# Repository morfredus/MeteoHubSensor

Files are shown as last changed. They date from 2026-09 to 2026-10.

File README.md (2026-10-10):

# MeteoHubSensor





> 🇫🇷 Version française : [README.fr.md](README.fr.md)

Standalone outdoor weather probe, linked over **ESP-NOW** to the **MeteoHub** station. Target board: **ESP32-S3 Super Mini** (RGB LED, no screen).

---

## 1. Responsibility

**MeteoHubSensor** has a single responsibility: **measure the outdoor environment and transmit its raw metrics over ESP-NOW**.

This node is **not a new morfSystem component**. No web server, no local history.

### Roles:
- **Super Mini (Outdoor)**: *"I measure, I blink the status, I transmit."*
- **MeteoHub**: *"I receive, validate, store, display and expose."*

---

## 2. ESP-NOW architecture

```
              ┌─────────────────┐
              │  ESP32-S3       │
              │  MeteoHub       │
              └────────┬────────┘
                       │ ESP-NOW
              ┌────────▼────────┐
              │  Super Mini     │
              │  RGB LED        │
              │  AHT20 / BMP280 │
              └────────┬────────┘
                       │
              ┌────────┴────────┐
              ▼                 ▼
         Temperature        Humidity
```

### Changing hub: pairing with a long press on BOOT

The probe talks to **a single** MeteoHub, in unicast. That hub's MAC is stored in
the probe's NVS: there is no need to know it at build time, nor to reflash to
change hub.

1. Leave **only** the MeteoHub to pair powered on within radio range
   (MeteoHub **≥ 1.46.0**).
2. With the probe running, hold **BOOT for about 3 s**, until the LED turns
   **solid blue**, then **release**: pairing starts on release. A press longer
   than 10 s is ignored (button considered stuck). Do not hold BOOT while
   plugging the probe in: that is the ESP32 flashing mode.
3. The probe sweeps channels 1 to 13 asking "who is a hub?". The hub answers with
   its identity and MAC; the probe confirms in unicast and waits for the hub's
   acknowledgement.
4. **3 green flashes**: paired, the new MAC is in NVS and measurements go to this
   hub in unicast. **3 red flashes**: failure, the previous association is **kept
   as it was**.

Rules:

- **Deliberate only.** A hub that is off or out of range never triggers a change
  of receiver: the probe keeps its measurements pending and keeps aiming at its
  hub.
- **A failure erases nothing.** Until a new hub has answered AND acknowledged the
  confirmation, the probe keeps the old MAC (in NVS and in memory).
- **Several hubs in range.** If two different hubs answer during the sweep, the
  probe refuses (red flashes) rather than pick one at random. Once paired, the
  other hubs can be switched back on: the probe finds ITS hub's channel through
  the exact BSSID of its "MH-NOW" access point, no longer through the first
  "MH-NOW" it sees.
- **No duplicate, no gap.** The confirmation carries the last measurement number
  acknowledged by the old hub: the new hub resumes from there and only receives
  the measurements still pending.
- **Stuck button = no effect.** A permanent press (an enclosure pressing the
  button, moisture on GPIO0) is never released: it starts no pairing, and the
  button wake-up is not even armed while GPIO0 stays low. Measurements carry on
  normally.
- Search bounded to **60 s**. A short press is ignored.
- The hub (≥ 1.47.0) **only archives the probe that chose it**: a bench probe
  powered on next to it can no longer mix its readings with the outdoor ones. The
  press wakes the probe from sleep; it then goes back to sleep for the remaining
  time, without shifting the measurement cadence.

Without a stored pairing (new probe, erased flash), the probe **sends nothing**:
`ESPNOW_RECEIVER_MAC` (`include/config.h`) is zero since 0.25.0. It keeps its
measurements pending and no longer scans channels until a long press on BOOT has
paired it. A hard-coded MAC would have targeted one specific hub, and after
swapping hubs (production ↔ test bench) an erased probe would have sent its
readings to the wrong hub.

### Local buffer: no measurement lost, without draining the battery

Each measurement is written to flash **before** it is sent, then kept until the
hub acknowledges it. If the hub is off or out of range, the probe later resends
what is missing, in order, at most 10 measurements per wake-up. Retention: 30
days of pending measurements.

Since 0.24.0 this buffer is a **segmented journal**: one small file per day of
measurements (`/mhs/<seq>.seg`), written by appending only. The acknowledgement
watermark lives in NVS, and a fully acknowledged segment is deleted. The former
buffer, a single 276 KB file, was copied in full by LittleFS at every
measurement: 4.5 s measured, radio on. On the first boot in 0.24.0, the
measurements still pending in the old file are taken over, then it is erased.

---

## 3. Hardware

The pinout lives in `include/board_config.h`, selected by the `SENSOR_BOARD_S3`
define set by the PlatformIO environment.

**ESP32-S3 Super Mini** (env `sonde-supermini`)
- 4 MB flash + 2 MB quad PSRAM (unused), native USB CDC. **No screen** (status on the LED).
- Status = RGB LED on GPIO 48 (blue acquisition, green OK, red error).
- **I2C**: SDA = GP8, SCL = GP9. Battery: Li-ion, 3.3 V regulator module, 100k/100k divider on GP4.
- ESP-NOW capped at **11 dBm** (hardware constraint confirmed by testing: full power = no ACK).
- **Sensors**: DHT22 on GP1 (reference for temperature and humidity, no fallback), BMP280 (pressure only; the AHT20 of the module is no longer read). Anemometer reserve on GP5.
- Details (French): [`docs/cablage.md`](docs/cablage.md).

---

## 4. RGB LED

- **Blue**: boot and acquisition.
- **Green**: delivery confirmed (the hub acknowledged, unicast ACK).
- **Red**: not delivered (no ACK from the hub).
- **Solid blue** (after ~3 s holding BOOT): pairing in progress.
- **3 green / red flashes**: pairing succeeded / failed (association unchanged).

---

## 5. Build and flash

1. Copy `include/secrets_example.h` to `include/secrets.h` **in this project**.

```bash
# ESP32-S3 Super Mini
pio run -e sonde-supermini
pio run -e sonde-supermini -t upload
pio run -e sonde-supermini -t monitor
```

If the serial port does not show up: hold BOOT, tap RESET, release BOOT.

---

## 6. Author & License

Developed by **morfredus** for the **MeteoHub** weather station.
License: **GPL v3**.

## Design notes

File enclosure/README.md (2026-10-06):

# enclosure

Premiere version d'un **mini ecran de Stevenson** pour la sonde, a imprimer en 3D.

- `stevenson-shelter-v1.scad` : modele OpenSCAD (V8), adapte du plan traditionnel a l echelle de la sonde.
  Volume interieur 110 x 90 x 110 mm, caisson exterieur 130 x 110 x 130 mm, 10 lames par face
  (110 x 8 x 4 mm, inclinees a 40 degres, pas de 11,2 mm), exterieur toujours plus bas sur les quatre faces.
- `stevenson-reference-plan.jpg` : page de reference du plan traditionnel (« La construction d une station
  meteo »). Document tiers : a garder dans ce depot prive, a ne pas publier tel quel.

Etat : premier jet, non imprime ni teste. Le but est de limiter l echauffement solaire du capteur
(variations brutales de temperature observees en plein apres-midi) tout en gardant une bonne circulation d air.

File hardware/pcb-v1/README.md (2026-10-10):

# Carte v1 de MeteoHubSensor (projet KiCad 10)

Platine dessinée pour remplacer la v1 montée sur platine à bandes (uPesy) : même schéma, mais gravée,
avec l'ESP32-S3 Super Mini sur supports pour pouvoir l'échanger sans dessoudage.

Ouvrir `meteohubsensor-v1.kicad_pro` avec KiCad 10.0.x. Fichiers : schéma, PCB routé (66 x 50 mm, deux
couches, plan de masse GND sur les deux faces), bibliothèque `morfsensor` (symboles et empreintes propres au projet).

## Ce que porte la carte

| Réf. | Rôle | Reliée à |
| :--- | :--- | :--- |
| U1 | ESP32-S3 Super Mini N4R2 sur 2 supports femelles 1x9 | voir ci-dessous |
| U2 | Module abaisseur 3,3 V (Youmi, SOT-223) | VIN = + accu, VOUT = rail 3V3 |
| J1 | Accu (JST-XH 2 broches : + / -) | VBAT, GND |
| J2 | BMP280 (JST-XH 4 broches : 3V3, SCL, SDA, GND) | GP9 (SCL), GP8 (SDA) |
| J3 | DHT22 (JST-XH 3 broches : 3V3, DATA, GND) | GP1 |
| J4 | Anémomètre, futur (3V3, IMPULSION, GND) | GP5 |
| J5 | Pluviomètre, futur (3V3, IMPULSION, GND) | GP7 |
| J6 | Girouette, future (3V3, ADC, GND) | GP2 |
| R1, R2 | Pont 100 kohm / 100 kohm sur le + accu, avant le régulateur | milieu = GP4 |
| C3 | 100 nF sur le noeud du pont (stabilise la lecture ADC) | GP4 / GND |
| C1, C2 | 100 nF céramique + 220 uF électrolytique, collés aux broches 3V3/GND du S3 | rail 3V3 |
| R3 | 10 kohm de rappel du DHT22 (omettre avec un module 3 broches qui l'embarque) | DATA / 3V3 |
| H1 à H4 | Trous de fixation M3 | |

Le régulateur alimente la broche **3V3** du S3 (pas la 5V), comme sur la v1 actuelle. Broches du S3 laissées
libres : TX, RX, GP3, GP6, 5V, GP10 à GP13.

## Masse et modèles 3D

La masse (GND) est un plan de cuivre sur les deux faces : toutes les broches GND des connecteurs et des
composants s'y raccordent par leurs pastilles traversantes, sans piste dédiée. Seules l'alimentation et les signaux
sont tracés. Des pistes GND explicites ont été
essayées puis retirées : elles alourdissaient le dessin sans rien apporter, le plan relie déjà tout.
Les empreintes `ESP32-S3_SuperMini_Socket` et `Regulator_Module_3V3` embarquent un modèle 3D simplifié
(`morfsensor.3dshapes/`) : supports et module avec USB-C et antenne, platine du régulateur avec SOT-223.

## Brochage des connecteurs JST-XH

Broche 1 à gauche (côté de l'ergot carré de l'embase), vue de dessus, détrompeur vers le bas.

| Connecteur | Broche 1 | Broche 2 | Broche 3 | Broche 4 | Référence suivie |
| :--- | :--- | :--- | :--- | :--- | :--- |
| J1 accu | + accu | - accu | | | rouge (+) puis noir (-), usage courant des accus Li-ion |
| J2 BMP280 | 3V3 | SCL | SDA | GND | + puis signaux puis GND, comme les autres ; SCL et SDA se relient sans croisement |
| J3 DHT22 | 3V3 | DATA | GND | | ordre de la fiche technique du DHT22 / AM2302 (VDD, DATA, GND) |
| J4 anémomètre | 3V3 | IMPULSION | GND | | même ordre que J3 |
| J5 pluviomètre | 3V3 | IMPULSION | GND | | même ordre que J3 |
| J6 girouette | 3V3 | ADC | GND | | même ordre que J3 |

Les modules BMP280 courants sont étiquetés dans un autre ordre (VCC, GND, SCL, SDA) : les câbles se sertissent à
l'ordre du connecteur de la carte, pas à celui du module.

## Orientation du module régulateur

Vue de dessus, broches vers le bas (soudées sur la carte), IN à gauche et OUT à droite : sur chaque paire,
VIN (gauche) et VOUT (droite) sont sur la broche du bas, GND sur la broche du haut.

## Repères des broches du S3

Les numéros de pastilles de U1 sont les repères imprimés sur le module, vue de dessus, USB en haut : à
gauche de haut en bas TX, RX, 1, 2, 3, 4, 5, 6, 7 ; à droite de haut en bas 5V, GND, 3V3, 13, 12, 11, 10, 9, 8.
Pastille 8 = GPIO8 = SDA, pastille 9 = GPIO9 = SCL, et ainsi de suite : aucune table de correspondance à tenir.
J6 (girouette) ne porte que le signal brut sur GP2 : le pont diviseur propre à la girouette reste à définir
avec le firmware.

## Antenne

Le S3 est implanté **USB vers l'intérieur** : l'antenne céramique se retrouve au **bord bas** de la carte.
Une zone d'exclusion (cuivre, pistes, vias, plan de masse, sur les deux faces) couvre l'espace sous l'antenne
et jusqu'au bord. Aucune piste n'approche l'antenne : les signaux des deux rangées partent vers l'extérieur.

Limite connue : l'USB du module est tourné vers l'intérieur de la carte. Pour flasher, enlever le module de
ses supports (c'est l'intérêt de la prise).

## Cotes relevées sur les modules

- **ESP32-S3 Super Mini** : 15,9 mm hors tout entre les deux rangées de broches, soit 15,24 mm entre axes (broche de
  0,64 mm), pas de 2,54 mm comme sur une platine d'essai. Empreinte `ESP32-S3_SuperMini_Socket`.
- **Module régulateur** : circuit de 25,6 x 11,3 mm. Broches standard (0,64 mm) sur la grille de 2,54 mm, comme les
  deux modules qui entrent dans une platine d'essai : deux paires espacées de 22,86 mm entre axes (9 pas) dans la
  longueur, pas de 2,54 mm dans chaque paire (3 mm hors tout dans la largeur). Empreinte `Regulator_Module_3V3`.
  La position des paires dans la largeur du circuit est supposée centrée : elle ne change que le contour dessiné,
  pas le perçage.

## À vérifier avant fabrication

1. **Module régulateur** : vérifier que son orientation réelle (IN à gauche, VIN sur la broche du bas) correspond à
   l'empreinte, en le posant sur la carte imprimée ou sur un gabarit.
2. **Connecteurs** : les câbles existants ne suivent pas forcément cet ordre ; les recréer au brochage du tableau.

Rappel du point de vigilance de `docs/cablage.md` : la plage d'entrée annoncée du module (4,5 à 7 V) est
au-dessus de celle d'un accu Li-ion. À mesurer sur banc avant de figer la carte.

## Contrôles passés (KiCad 10.0.7, `kicad-cli`)

- ERC : 0 violation.
- DRC avec parité schéma/PCB : 0 erreur, 0 piste non connectée. Restent des avertissements de sérigraphie
  (textes proches des contours de connecteurs).

Les fichiers ont été générés par script puis vérifiés par ces commandes ; les ouvrir une fois dans KiCad et
lancer `Fichier > Enregistrer` les remet au format exact de l'éditeur.

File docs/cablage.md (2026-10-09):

# Câblage et fonctionnement - MeteoHubSensor

Sonde météo extérieure autonome, reliée à la station **MeteoHub** par **ESP-NOW**.
Carte cible : **ESP32-S3 Super Mini** (`sonde-supermini`) - LED RGB seule (pas d'écran,
pour réduire la consommation), TX ESP-NOW plafonnée (11 dBm).

> La liaison est un **unicast** vers la MAC du hub : chaque envoi reçoit un accusé
> de réception matériel (ACK). La carte plafonne sa puissance d'émission (l'antenne
> PCB du Super Mini est mal adaptée : à pleine puissance, le hub n'acquitte pas).
> Le niveau se règle dans `include/config.h`.
> Antenne filaire essayée en prod depuis le 2026-10-06 : voir `docs/notes.md`, section 5.

Le brochage vit dans `include/board_config.h` (sélectionné par `SENSOR_BOARD_S3`) et
les réglages dans `include/config.h`.

---

## 1. Brochage - ESP32-S3 Super Mini

USB natif sur GPIO 19/20. BOOT sur GPIO 0. Straps 45/46 (GP46 input-only).

| Broche | GPIO | Usage firmware |
| :--- | :--- | :--- |
| **3V3** | -- | Alim capteurs I2C |
| **GND** | -- | Masse |
| **GP8** | 8 | I2C **SDA** (BMP280 ; AHT20 non lu) |
| **GP9** | 9 | I2C **SCL** |
| **GP48** | 48 | LED RGB **WS2812** onboard (pas GP46) |
| **GP0** | 0 | Bouton **BOOT** |
| **GP4** | 4 | ADC batterie (`PIN_BATTERY_ADC = 4`) : pont 100k/100k depuis le **+ accu** (avant le régulateur 3,3 V) |
| **GP1** | 1 | DHT22 DATA (référence température et humidité) |
| **GP2** | 2 | Girouette ADC (réserve) |
| **GP7** | 7 | Pluviomètre (réserve) |
| **GP10** | 10 | ADC auxiliaire (réserve) |
| **GP5** | 5 | Anémomètre (réserve) |
| **GP6** | 6 | Libre |

- **Pas d'écran** : le statut passe par la LED RGB et le log USB CDC.
- **TX ESP-NOW plafonnée à 11 dBm** : à pleine puissance, le hub n'acquitte aucune
  trame (antenne PCB du Super Mini mal adaptée). Réglable via le menu de `config.h`
  (`SENSOR_TX_POWER_LEVEL` ; la carte le demande via `SENSOR_NEEDS_TX_LIMIT`).
- La LED RGB onboard est sur **GPIO 48**. Le pinout constructeur annote parfois
  DIN WS2812 = GP46 : sur ESP32-S3, GP46 ne peut pas la piloter. Si la LED reste
  éteinte après flash, tester GPIO 47 (certains clones Lolin).

---

## 2. Capteurs I2C

```
Carte                     Module BMP280 / AHT20
┌──────────┐              ┌─────────────────────┐
│      3V3 ├─────────────►│ VCC (3.3V)          │
│      GND ├─────────────►│ GND                 │
│  SDA     ├─────────────►│ SDA                 │
│  SCL     ├─────────────►│ SCL                 │
└──────────┘              └─────────────────────┘
```

- SDA/SCL : **GP8/GP9**.
- Adresses : AHT20 = 0x38, BMP280/BME280 = 0x76 ou 0x77.
- Pull-up I2C : la plupart des modules AHT/BMP les intègrent ; sinon 4,7 kΩ vers 3V3.

---

## 3. Alimentation batterie

**Module régulateur 3,3 V + accu Li-ion** (cellule 3,7 V, 3000 mAh depuis le 2026-10-03).
Un petit module **Youmi « 3.3 V DC/DC abaisseur »** (boîtier SOT-223, une LED sur la sortie,
bornes IN + GND et OUT + GND en 2 broches, 26 x 12 x 12 mm) abaisse la tension de l'accu en un
**3,3 V** pour la carte. Annoncé par le vendeur : entrée **4,5 à 7 V CC**, sortie 3,3 V CC,
800 mA. Le
même module équipe la v1 (prod) et la v2 (banc), voir la section 5.

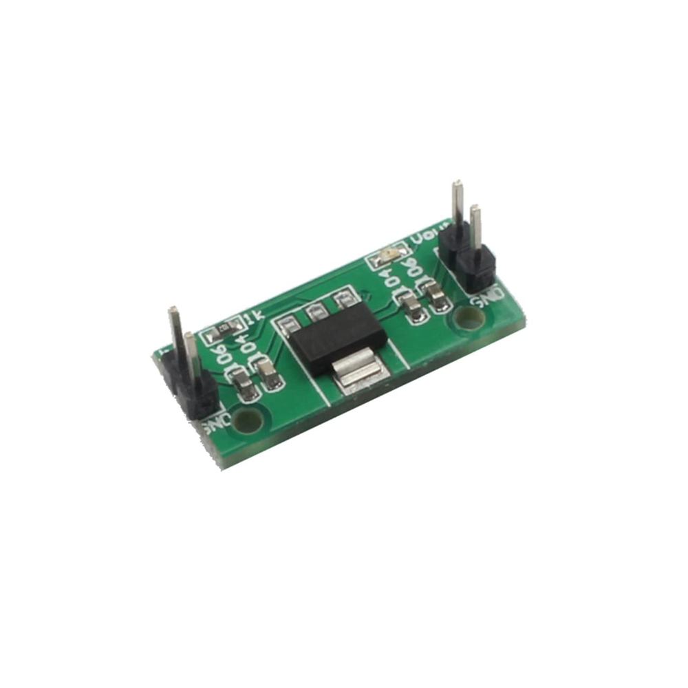
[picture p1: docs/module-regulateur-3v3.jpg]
Module régulateur 3,3 V


Câblage du module, identique sur la v1 et la v2 : l'**accu** est branché sur **VIN et GND** du
régulateur ; le module distribue le **3,3 V** (VOUT) et la **masse** (GND) à la carte.

Il remplace le module **Breadvolt** (boost AP2004H) des premières versions, qui semblait
décrocher à la charge très faible du deep sleep (voir l'essai light sleep dans
`include/config.h`). Le Breadvolt n'est plus monté sur la carte de prod.

**Charge de l'accu.** Le Breadvolt gérait lui-même l'accu (protection décharge 2,4 V, charge
4,28 V, LEDs CHG/PWR). Ce n'est plus le cas : le module régulateur ne fait ni charge ni
protection. L'accu est chargé **hors de la sonde, dans un chargeur de bureau** ; il n'y a **pas de
charge par USB** dans cette version. L'usage visé est de disposer de **deux accus** et de
remplacer l'accu usé par l'accu chargé quand c'est nécessaire.

> **Point de vigilance (à mesurer)** : la plage d'entrée annoncée du module (4,5 à 7 V) est
> **au-dessus** de celle d'un accu Li-ion (2,6 à 4,2 V). Hors plage, la sortie n'est plus un 3,3 V
> régulé : elle suit l'accu, diminuée de la tension de déchet (dropout) du régulateur. Le S3
> décroche alors bien avant que l'accu soit vide (brownout vers 2,4 à 3,0 V de rail). Mesurer
> VOUT en fonction de la tension d'accu, sur le banc, pour connaître l'accu minimal utilisable et
> le comparer aux seuils d'alerte de MeteoHub (3,40 V puis 3,20 V).

- Le 3,3 V régulé est **constant** : le mesurer ne dirait rien de l'accu. On tape donc
  la **cellule**, **avant** le régulateur, au **+ accu** (multimètre ~4,0 V en charge).
- Cet accu monte à **4,28 V** en pleine charge : il ne doit **jamais** arriver brut sur
  la pin (limite ADC du S3 ~3,3 V). Un **pont 100 kΩ / 100 kΩ** divise la tension par
  deux et GP4 lit le point milieu :

  ```
  + accu ──[R1 100k]──┬── GP4 (ADC1)
                      │
                   [R2 100k]
                      │
                     GND
  ```

  GP4 voit ~2,0 V pour 4,0 V accu ; le firmware remultiplie par le ratio du pont
  (`BATTERY_DIVIDER_RATIO = 2,0`) et convertit en pourcentage par une **courbe de charge Li-ion par paliers**
  (`include/battery_curve.h`, testée par `pio test -e native`), pas par une droite : à 3,7 V
  il reste ~15 %, pas 69 %.
  `PIN_BATTERY_ADC = 4` (activé le 2026-09-15).
- Le pont draine en continu ~4,0 V / 200 kΩ ≈ **20 µA**, négligeable devant les
  réveils d'émission.
- **Accu actuel (2026-10-03)** : Li-ion 3,7 V **3000 mAh** (remplace le 14500 de 500 mAh).
- **Calibration fine** : si la tension rapportée par la sonde diffère de
  ton multimètre (tolérance des résistances + offset ADC), poser
  `BATTERY_VREF_CALIBRATION = tension_multimètre / tension_rapportée` (× facteur actuel) dans
  `board_config.h`. **Posé le 2026-10-03 : 1,036** (moyenne de deux relevés multimètre / sonde : 3,927 V pour 3,98 V et 4,074 V pour 4,14 V ; résidu < 0,3 %). À revérifier à pleine charge stable et à mi-charge.
- Filet de sécurité : quand l'accu se vide, le pourcentage tombe à 0 % (0 % calé à
  2,6 V, **seuil confirmé**, 0,2 V au-dessus de l'ancienne coupure 2,4 V du Breadvolt), puis la
  sonde s'arrête (MeteoHub voit **OUT absent**). Voir le point de vigilance ci-dessus : le rail 3,3 V
  peut décrocher avant que l'accu atteigne ce seuil.

---

## 4. LED de statut (WS2812 / NeoPixel)

La carte porte **une LED RGB adressable WS2812** (NeoPixel), pas une simple LED. Le
firmware l'utilise comme **témoin d'activité et de résultat d'émission**, en luminosité
douce (pour ne pas éblouir de nuit ni trop consommer). Il n'y a **pas d'écran** : cette
LED est le seul retour visuel local.

| Couleur | Quand | Signification |
| :--- | :--- | :--- |
| 🔵 **Bleu** | Au démarrage, puis pendant **chaque acquisition** de mesure | « Je travaille » : lecture des capteurs et préparation de la trame en cours |
| 🟢 **Vert** (bref) | Juste après l'envoi ESP-NOW, si le hub a **accusé réception** | La trame est **livrée** (ACK reçu du hub) |
| 🔴 **Rouge** (bref) | Juste après l'envoi ESP-NOW, si **aucun ACK** n'est revenu | La trame **n'a pas été livrée** (hub hors de portée / éteint) |
| 🔴 **Rouge fixe** | Au boot, si l'init ESP-NOW échoue | Radio ESP-NOW indisponible (défaut au démarrage) |
| 🔵 **Bleu fixe** | Après ~3 s d'appui sur **BOOT** | Relâcher : l'appairage démarre au relâchement (recherche d'un hub, 60 s max). Au-delà de 10 s d'appui, rien ne se passe (bouton coincé) |
| 🟢 **3 éclairs verts** | Fin d'appairage | Nouveau hub enregistré, mesures redirigées vers lui |
| 🔴 **3 éclairs rouges** | Fin d'appairage | Aucun hub, plusieurs hubs, ou pas d'accusé : **association inchangée** |
| ⚫ **Éteinte** | Au repos entre deux mesures (et avant la mise en veille) | Rien à signaler / cycle terminé |

Précisions importantes :

- **Vert = trame réellement livrée.** L'envoi est un **unicast** vers la MAC du hub :
  la couche radio renvoie un ACK matériel. Le vert confirme donc que MeteoHub a bien
  reçu la trame (et non seulement qu'elle est partie) ; le rouge signale l'absence
  d'ACK (hub éteint, hors de portée, ou mauvais canal).
- Le clignotement vert/rouge est **court** (~60 ms) : à chaque cycle de mesure
  (5 min par défaut), on voit un bref éclat, puis la LED s'éteint.
- En **mode veille profonde** (si activé), la LED est éteinte avant le sommeil pour ne
  rien consommer ; chaque réveil rejoue la séquence bleu → vert/rouge.

Le pilotage est dans `src/modules/power_manager.cpp` (`setLedColor`, `blinkStatus`,
`turnOffLed`), déclenché depuis `src/main.cpp`.

---

## 5. Cartes v1 et v2

Deux platines à bandes portent le même montage : un ESP32-S3 Super Mini sur barrettes
femelles, le module régulateur 3,3 V, le pont de mesure de batterie (100 kΩ / 100 kΩ vers GP4),
un condensateur électrolytique et une céramique près de l'alimentation, et **trois prises JST**
(accu, signaux I2C, alimentation du capteur).

### v1 : platine uPesy, sonde de production (boîtier extérieur)

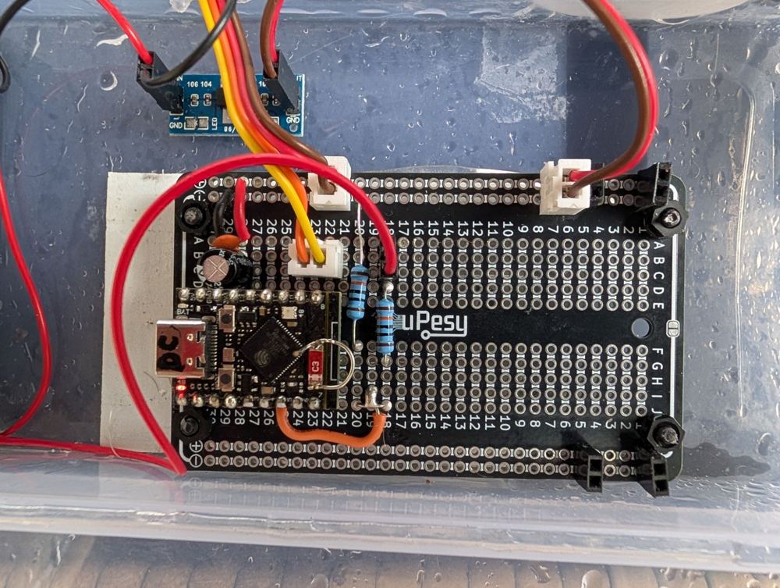
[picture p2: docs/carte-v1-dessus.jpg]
Carte v1, vue de dessus

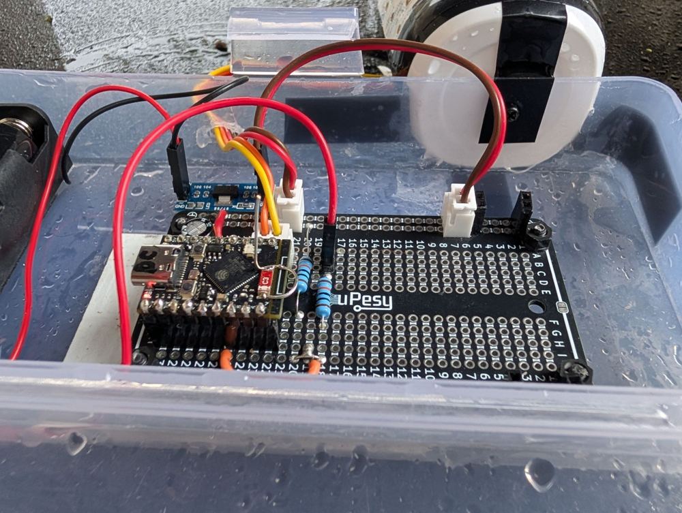
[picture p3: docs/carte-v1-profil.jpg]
Carte v1, profil

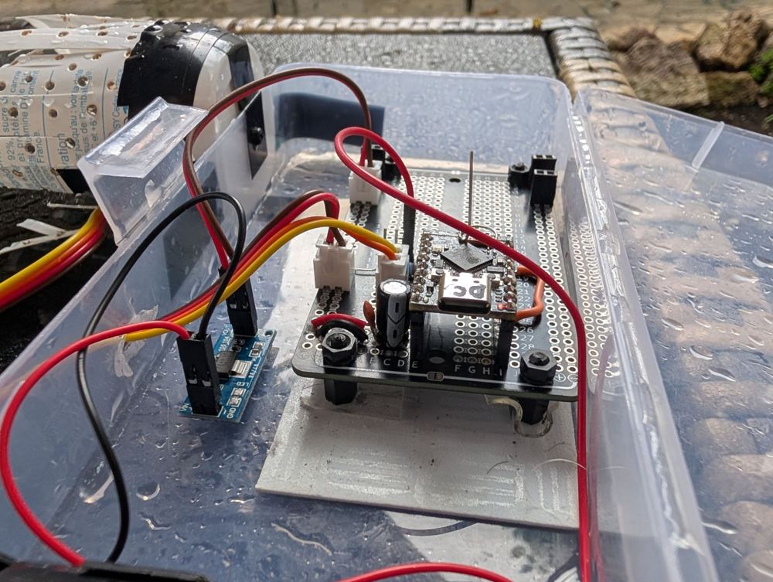
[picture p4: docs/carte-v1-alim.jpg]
Carte v1, côté alimentation


- Platine noire **uPesy**, grand format, dans un boîtier transparent.
- Les **4 supports Dupont 2 broches** de la carte accueillaient le **Breadvolt**, retiré depuis.
- Le **module régulateur** n'est pas sur ces supports : sa **sortie** se branche sur le **JST voisin**
  de ces supports, sur le **rail d'alimentation** de la carte ; son entrée (VIN, GND) reçoit l'accu.
- Le S3 Super Mini porte l'**antenne filaire maison** (voir `docs/notes.md`, section 5).
- Les deux résistances de 100 kΩ et un fil orange vers la broche GP4 forment le pont de mesure.

**Carte gravée.** Le dessin KiCad de la v1 (mêmes fonctions, S3 sur supports, antenne en bord de carte) est dans
`hardware/pcb-v1/` ; voir son `README.md` pour les cotes à vérifier avant fabrication.

### v2 : platine Electrocookie, banc

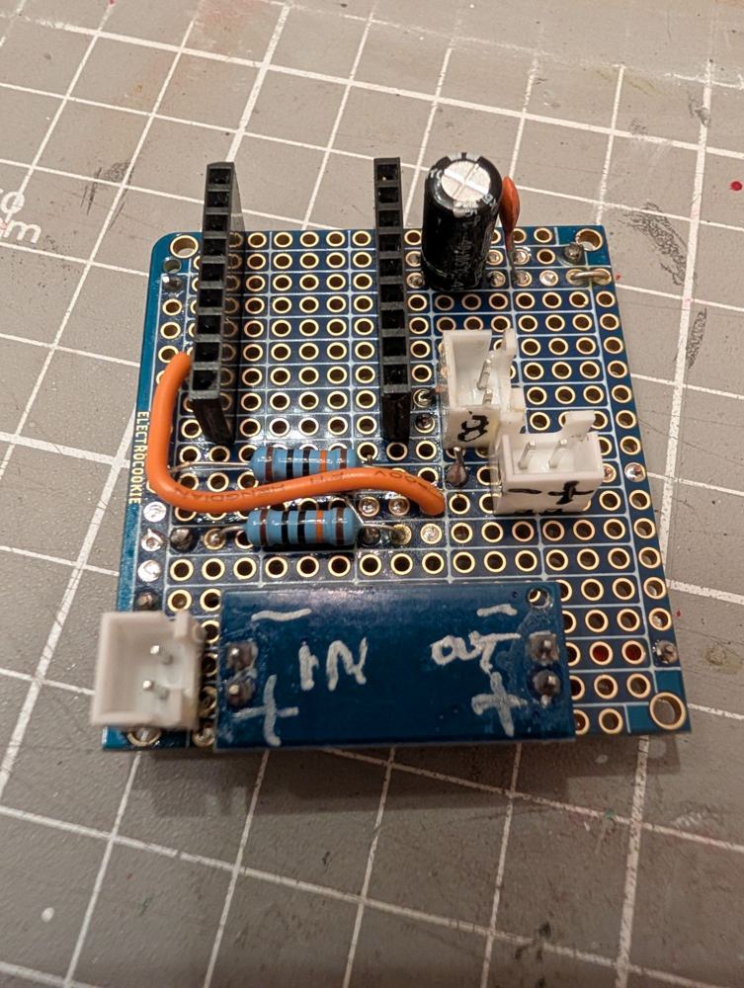
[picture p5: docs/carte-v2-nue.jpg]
Carte v2 nue

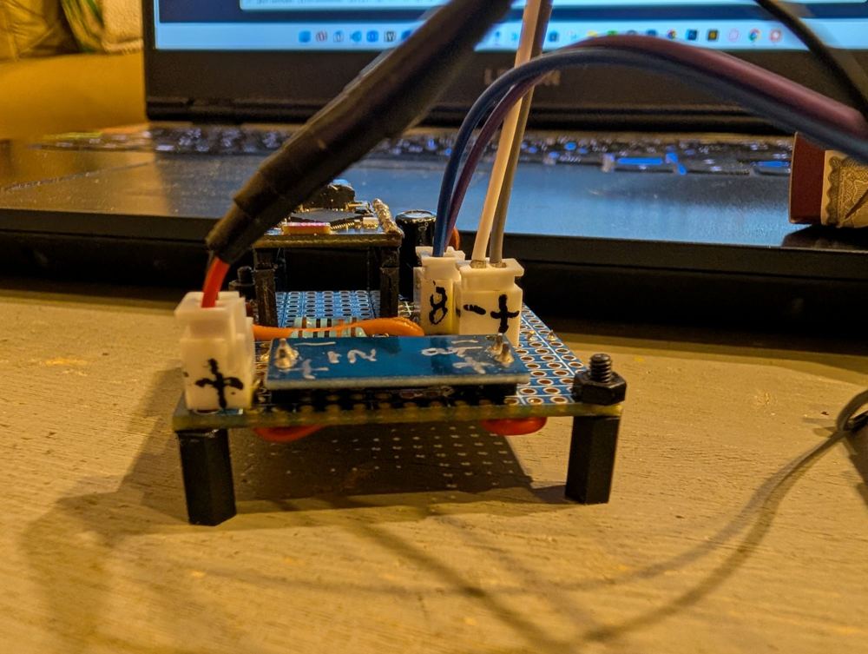
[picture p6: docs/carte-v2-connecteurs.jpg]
Carte v2, connecteurs

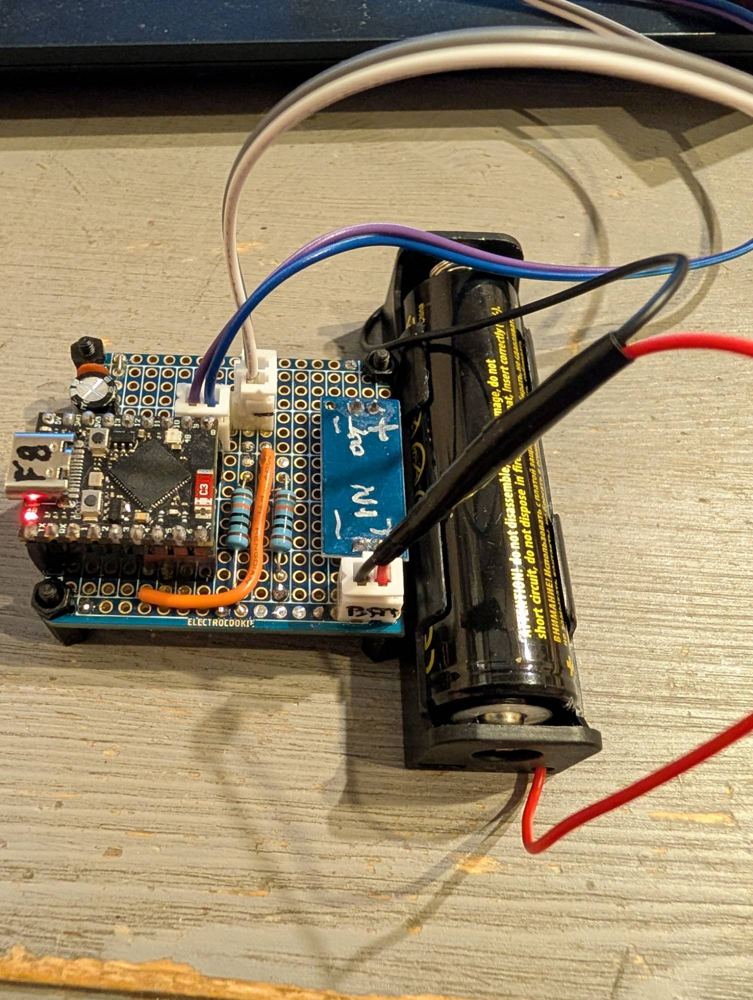
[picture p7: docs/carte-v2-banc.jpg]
Carte v2 sur le banc

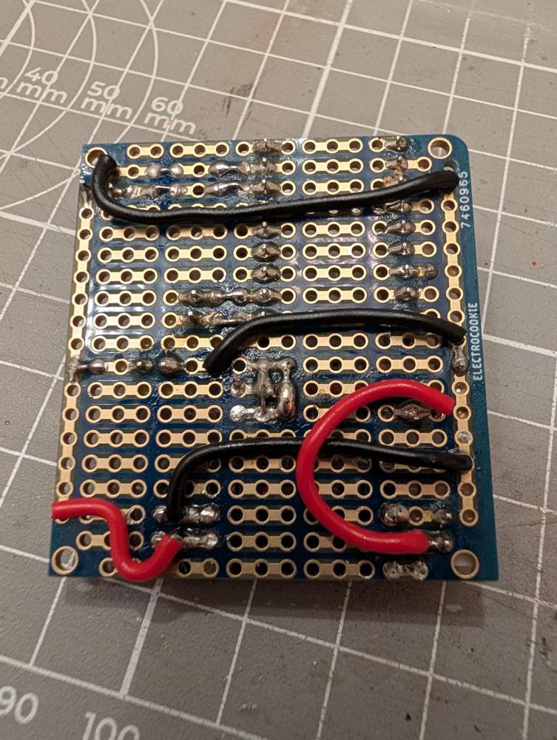
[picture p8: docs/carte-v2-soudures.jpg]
Carte v2, face soudures


- Platine bleue **Electrocookie**, compacte, sur **quatre entretoises** (elle tient debout sur
  le banc et se fixe dans un boîtier).
- **Même nombre de JST que la v1**, repérés au feutre : **BAT** (accu), **8** (SDA GP8 et
  SCL GP9) et **- +** (masse et alimentation du capteur). Le câble Dupont à quatre broches du
  capteur se branche sur les deux derniers.
- Le **module régulateur** est soudé directement sur la carte, ses côtés marqués « IN + - » et
  « OUT + - » au feutre. C'est la différence de montage avec la v1.
- Le S3 Super Mini est sur barrettes femelles, comme sur la v1.
- Sur le banc, le S3 n'a **pas** l'antenne filaire. Le multimètre se pique sur la prise BAT.
- Les liaisons sous la carte sont faites au fil isolé et par ponts de soudure sur les bandes.
- État (2026-10-07) : la v2 mesure et enregistre correctement, mais **aucune trame n'arrive au hub**, 
  avec un S3 équipé de l'antenne filaire comme avec un S3 sans antenne. Hypothèse (non démontrée) : 
  perturbation radioélectrique due aux liaisons sous la carte. Sortir le S3 de la carte n'y change rien, et la zone d'antenne ne peut pas être dégagée
  sans perdre l'intérêt de la v2 (réduire la taille). Même à côté du hub, aucune communication : **la v2 est un échec
  pour son objectif**. La v1 modifiée pour le DHT22 reste la carte de prod et fonctionne dès le premier démarrage.
  Voir `notes.md`, section 7.

### v3 : envisagée

Une v3 de la carte est envisagée avec un **petit panneau solaire** et un **chargeur solaire** couplé
à une **batterie protégée**. Elle supprimerait le remplacement manuel des accus et la question de la
protection de décharge. Rien n'est défini à ce stade (références, câblage, place du régulateur).

Piste d'implantation tirée de l'échec de la v2 (intuition de Fred, **non testée**) : sur la v2, l'antenne du S3 se
retrouve au milieu de la carte. Implanter le S3 dans l'autre sens pour que l'antenne soit **en bordure de carte**,
dégagée des fils et des plans de cuivre.
La question de la plage d'entrée du régulateur (voir la section 3) se reposera avec ce chargeur.

### Différences

| Sujet | v1 (uPesy, prod) | v2 (Electrocookie, banc) |
| :--- | :--- | :--- |
| Platine | Grande, noire, boîtier transparent | Compacte, bleue, quatre entretoises |
| Module régulateur | Sortie sur le JST voisin des 4 supports Dupont (ex-Breadvolt), sur le rail d'alimentation | Soudé sur la carte |
| Prises JST | 3 (accu, I2C, alim capteur) | 3 (BAT, 8, - +) |
| ESP32-S3 | Sur barrettes, antenne filaire | Sur barrettes, sans antenne filaire (à changer) |
| Mesure batterie | Pont 100 k / 100 k vers GP4 | Identique |

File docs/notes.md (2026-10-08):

# Notes d'architecture et choix techniques - MeteoHubSensor

## 1. Pourquoi ESP-NOW ?

L'objectif principal de ce projet est de déporter l'acquisition météo dans le jardin ou sur un balcon sans créer de fragilité sur le réseau :

- **Indépendance vis-à-vis du réseau local** : Si la box internet plante, redémarre ou change de mot de passe, l'acquisition météo ne s'arrête pas une seule seconde.
- **Ultra-faible consommation** : L'association Wi-Fi complète (DHCP, négociation WPA2, échange de clés) prend généralement entre 1.5 et 3 secondes. Avec ESP-NOW, la trame est émise en moins de 15 millisecondes dès le réveil.
- **Simplicité opérationnelle** : Aucun serveur web ou pile réseau complexe sur la sonde extérieure.

---

## 2. Consommation et autonomie sur batterie

### Bilan de consommation estimé :
1. **Phase de mesure et émission** (durée ~60 ms) :
   - Réveil + initialisation I2C : ~20 ms @ 20 mA
   - Mesure AHT20/BMP280 : ~15 ms @ 5 mA
   - Émission radio ESP-NOW : ~15 ms @ 120 mA
   - Énergie par cycle : environ \(0.002 \text{ mAh}\) par mesure.

2. **Phase de veille profonde (Deep Sleep)** :
   - ESP32-S3 Super Mini en deep sleep : plus gourmand que le C3 (LDO + USB
     PHY). Compter quelques dizaines de µA, à mesurer sur la carte réelle.
   - S'ajoute le **pont de mesure batterie** (100k/100k sur le + accu) qui draine
     ~20 µA en continu. Négligeable ici, mais présent aussi pendant le deep sleep :
     pour le supprimer, on pourrait commander le pont par un GPIO (MOSFET) ; jugé
     inutile vu l'ordre de grandeur.

### Autonomie théorique :
- La cadence réelle est de **5 minutes** (`SENSOR_MEASUREMENT_INTERVAL_SECONDS`, configurable) : bien plus économe qu'une mesure par minute, l'essentiel du temps étant passé en deep sleep.
- Le nœud de prod actuel (S3 Super Mini + module régulateur 3,3 V Youmi + accu Li-ion ; 500 mAh au départ, **3000 mAh** depuis le 2026-10-03 ; deux accus à permuter, chargés dans un chargeur de bureau) tient plusieurs jours ; l'autonomie exacte reste à mesurer sur la carte réelle (le S3 dort moins efficacement que le C3 à cause du LDO et du PHY USB).
- Avec une cellule plus grosse (14500/18650) ou un petit panneau solaire + module de charge, le système peut viser une autonomie longue durée. Chiffres à confirmer par la mesure terrain, pas par le calcul seul.

---

## 3. Synchronisation du canal Wi-Fi

ESP-NOW n'existe que sur **le canal de l'AP** auquel MeteoHub est associé.

La sonde repère le canal grâce à l'AP `MH-NOW` du hub, puis envoie en unicast.
La MAC du hub vient de la NVS, écrite par l'appairage (appui long sur BOOT, voir
le README). Une fois appairée, la sonde cherche le BSSID exact de l'AP de SON
hub : plusieurs hubs peuvent cohabiter. `ESPNOW_RECEIVER_MAC` (`config.h`) vaut
zéro : sans appairage enregistré, la sonde n'envoie rien et attend un appui long.
Le statut local est la LED RGB et le moniteur série (plus d'OLED sur la sonde).

- Copier `include/secrets_example.h` vers `include/secrets.h` ici (ignoré par git).
- Si le SSID n'est pas vu : canal RTC, sinon repli `ESPNOW_WIFI_CHANNEL_FALLBACK`.
- Côté station, la page OLED **Net.** affiche canal STA et MAC : les deux doivent coller.

---

## 4. Évolution et extensibilité

Le protocole utilise un champ `valid_fields` (masque binaire 16 bits). Cela permet à MeteoHub S3 de savoir instantanément quelles données sont fiables et présentes :

- Si seule la sonde AHT20 est branchée : seuls les bits `FIELD_TEMPERATURE` et `FIELD_HUMIDITY` sont actifs.
- Lorsqu'un anémomètre est ajouté ultérieurement : le bit `FIELD_WIND_SPEED` est activé, et MeteoHub commence automatiquement à enregistrer et afficher le vent sans casser la compatibilité des anciennes trames.

---

## 5. Retour terrain : sonde de prod remplacée par une carte avec antenne filaire (2026-10-06)

**Info importante : matériel.** La sonde de prod est une **ESP32-S3 Super Mini N4R2** (4 Mo flash,
PSRAM 2 Mo quad). L'ancienne sonde (MAC 3C:0F:02:E2:C7:D4, vue du hub `E2:C7:D4`) et la nouvelle
(AC:27:6E:CC:B2:DC, vue du hub `CC:B2:DC`) sont **le même modèle de carte** : la comparaison ne
mélange pas deux puces. Le C3 (HW-675) n'existe que sur le banc, jamais en prod. Ne pas déduire
le modèle d'une MAC (le préfixe ne distingue pas S3 et C3).

**Attention au mot « C3 » : l'inscription « C3 » sur la puce céramique rouge de la carte est le
marquage de l'antenne céramique, commune aux Super Mini ESP32-C3 et ESP32-S3. Ce n'est pas le
SoC : une carte S3 porte bien ce « C3 » sur son antenne.**

- Nouvelle sonde : carte avec une antenne filaire ajoutée autour de l'antenne céramique. Fil rigide 20 AWG
  (0,5 mm), 35 mm au total : 15 mm en vertical, le reste forme la boucle autour des deux côtés de
  l'antenne céramique. Photo du montage : `docs/antenne-filaire-g2.jpg` (mesures faites avec le banc d'essai Wi-Fi). Géométrie très
  sensible : 1 mm de boucle a valu ~9 dB sur le banc.
- Banc Wi-Fi (même carte, même endroit) : RSSI moyen -53,2 dBm sans antenne, -42,2 avec la 1re
  géométrie (34 mm), -33,4 avec la 2e (35 mm), 0 % de perte dans tous les cas. Ces mesures
  démontrent une amélioration importante du RSSI, mais pas encore une augmentation mesurable de la
  fiabilité de la liaison : le taux de perte était déjà de 0 % sans antenne dans ces conditions
  de test.
- Appairage du 2026-10-06 à 00:37 : 5 demandes en ~1 s, réponse du hub canal 11, sonde associée ;
  1re trame vivante à 00:42, `seq=1` sans mesures valides (ignorée par le hub), `seq=2` et `3`
  valides, rattrapage complet (`want=0/0`). Réveil `up=2s`, comme l'ancienne sonde.
- **Référence à comparer** : dernière ligne ESP-NOW du hub avec l'ancienne sonde : `rx=107 ok=107
  bad=0 rssi=-37` (canal 11). Comparer avec la ligne `src=...CC:B2:DC` suivante.
- Impression (non chiffrée, observation subjective à confirmer par une mesure) : association Wi-Fi plus rapide qu'avec la carte nue.
- TX ESP-NOW toujours plafonnée à 11 dBm par le firmware (`SENSOR_NEEDS_TX_LIMIT`) : à pleine
  puissance le hub n'acquittait pas avec l'antenne PCB d'origine. Non retesté avec l'antenne
  filaire ; sur le banc, une des deux cartes ne s'associait pas à 19,5 dBm (avec ou sans fil),
  l'autre oui : le comportement à pleine puissance dépend de la carte individuelle.
- À suivre : RSSI/ACK vus par le hub, courbe de batterie du hub (>= 1.59.0), tenue du fil à la
  pluie et au vent.

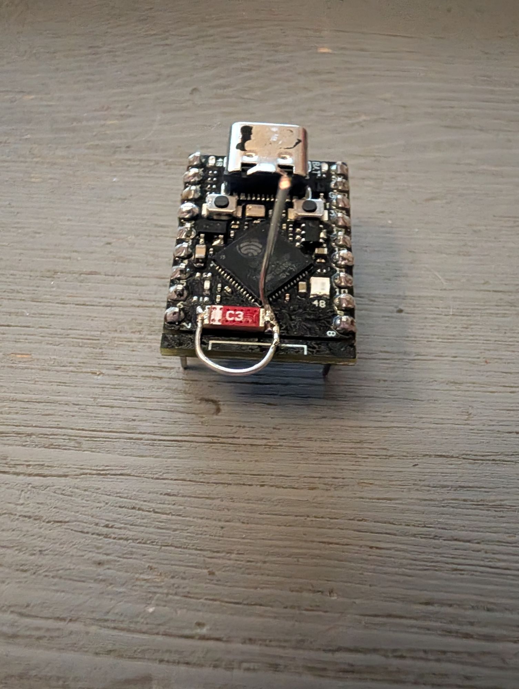
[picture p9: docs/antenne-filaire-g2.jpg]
Antenne filaire G2


**Sources de l'idée.** Fiche de la carte sur espboards.dev (encart « Good to know » : sur certaines
S3 Super Mini, l'antenne céramique est montée à l'envers, la piste d'alimentation ne touche alors
pas l'élément ; le point d'alimentation est du côté de la barre blanche) et l'article Hackaday
[Simple antenna makes for better ESP32-C3 WiFi](https://hackaday.com/2025/04/07/simple-antenna-makes-for-better-esp32-c3-wifi/)
(2025-04-07), qui décrit un fil quart d'onde de 31 mm. L'idée est cohérente avec une antenne quart d'onde à
2,4 GHz, soit environ 31 mm dans l'air. Le montage réellement retenu fait 35 mm de fil, mais sa
géométrie autour de l'antenne céramique fait partie intégrante du montage. Piste à vérifier si une carte
s'associe mal : l'orientation de l'antenne avant d'accuser la puce.

**Comment on en est arrivé là.** Aucune antenne n'était prévue. L'information est venue d'une
lecture sur espboards.dev, puis de l'article Hackaday : « quart d'onde, 2,4 GHz, environ 31 mm »
a rappelé les antennes de la CB. Un bout de fil 20 AWG a suivi, puis un banc d'essai Wi-Fi pour
vérifier que l'idée tenait.

## 6. DHT22 : référence température et humidité (0.30.0, étendu en 0.31.0)

- **Pourquoi le DHT22 en priorité** : dans l'installation réelle, le DHT22 est mieux isolé que le module
  AHT20/BMP280. Il donne un relevé hygrométrique plus réaliste et ne se bloque pas à 100 % (l'AHT20, lui,
  sature). Le critère est donc le comportement sur le terrain, pas la précision de la fiche technique ni l'écart du
  banc (voir le point suivant).
- **Principe (0.31.0)** : température et humidité viennent du DHT22 (GP1) seul. Le module BMP280+AHT20 ne sert plus
  qu'à la pression atmosphérique ; l'AHT20 n'est plus lu (bibliothèque retirée). Plus de repli : si le DHT22 est
  muet ou renvoie une trame invalide, température et humidité restent absentes du paquet (bits de validité à 0)
  plutôt que d'être remplacées par une valeur jugée moins fiable. Avant 0.31.0 : humidité DHT22 avec repli AHT20,
  température AHT20. Pas de détection à part : chaque cycle retente, un DHT22 absent échoue en quelques ms.
- **Pourquoi le DHT22 devient aussi la référence de température** : mêmes constats que pour l'humidité. Le relevé
  est plus stable et plus réaliste que celui de l'AHT20 du module, et un capteur unique pour les deux grandeurs
  évite un couple température/humidité venant de deux endroits physiques différents (l'humidité relative dépend
  directement de la température au point de mesure).
- **Calibration de l'humidité (2026-10-08)** : la sonde a été placée dans une atmosphère de solution saline saturée
  (NaCl), qui impose naturellement environ 75 % d'humidité relative. La sonde a rendu 75,0 à 75,1 % pendant 2 heures,
  stable et sans dérive : elle est considérée comme bien calibrée, aucun correctif nécessaire. Les constantes
  `DHT22_HUM_OFFSET` et `DHT22_TEMP_OFFSET` (`board_config.h`, à 0) restent disponibles pour une future recalibration.
- **Banc** (projet `40-test/dht22-aht-compare`, 813 mesures sur 42 min, 2026-10-07) : températures BMP280 - AHT20 =
  +0,06 °C (σ 0,02), DHT22 - AHT20 = -0,17 °C (σ 0,18) ; humidité DHT22 - AHT20 = -2,2 points (de -1,1 à -4,0,
  corrélation 0,92, écart en réduction au fil de la mesure) ; pression 1012,2 à 1013,0 hPa. Sans hygromètre de
  référence, on ne sait pas lequel est le plus juste ; offset d'affichage possible dans l'UI du banc.
- **Piège** : le type doit être DHT22. Avec DHT11 codé, la valeur lue ressemble à la température.
- **Conso estimée** (non mesurée) : environ 15 µA de repos (capteur alimenté en permanence), soit +4 % sur un cycle
  de 300 s ; lecture négligeable (quelques ms à 1,5 mA). Couper l'alimentation coûterait plus (1 à 2 s d'éveil).
  À confirmer au multimètre, DHT22 branché puis débranché.

## 7. Essai de la carte v2 en conditions réelles : aucune trame reçue (2026-10-07)

- **Contexte** : 0.30.0 en prod sur la v1 (DHT22 prioritaire pour l'humidité, repli AHT20), communication ok ;
  l'origine de l'humidité (DHT22) est transparente côté hub. Essai ensuite de la carte v2 (Electrocookie).
- **Constat** : avec la v2, **aucune trame n'arrive sur le hub**. Deux essais : un ESP32-S3 Super Mini équipé de
  l'antenne filaire, puis un autre sans antenne. Même résultat. La v2 mesurait et enregistrait pourtant bien (buffer
  de synchronisation).
- **Hypothèse (non démontrée)** : perturbations radioélectriques dues aux liaisons faites sous la carte (fil isolé,
  ponts de soudure sur les bandes), proches de l'antenne ou de la puce.
- **Pistes écartées** : sortir le S3 de la carte ne résout pas le problème. Dégager la zone d'antenne est impossible
  sans abandonner l'objectif de la v2 (réduire la taille). Même posée à côté du hub, la carte ne communiquait pas.
  La cause exacte reste donc inconnue.
- **Conclusion** : la v2 est un échec pour son objectif (carte plus compacte) ; la v1 reste la carte de production.
- **Retour** : carte v1 remise en place, modifiée pour accueillir le DHT22 ; fonctionnement ok dès le premier
  démarrage.
- **Rattrapage** : la sonde est revenue après 35 min de silence. Le hub a reçu le live seq=562 puis 6 retransmissions
  (seq 557 à 561), toutes archivées sans trou, puis un cycle normal (seq=563, réveil DEEPSLEEP). La synchronisation
  avec accusé cumulatif joue donc son rôle sur une coupure de 35 min.
- **Démarrage à froid** : la 1re mesure (reset POWERON, up=8s, t=20,0 °C) est jugée non conforme, archivée avec la
  marque `cold_boot` et exclue de l'affichage ; la carte venait d'être alimentée, donc encore chaude. Les
  retransmissions gardent `reset=POWERON` puisque ces mesures datent du démarrage.

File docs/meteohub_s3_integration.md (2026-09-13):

# Intégration côté MeteoHub (ESP32-S3)

Ce guide détaille comment intégrer la réception ESP-NOW sur la station **MeteoHub (ESP32-S3)**.

---

## 1. Structure du paquet

Copier le fichier `include/meteo_packet.h` de `MeteoHubSensor` dans le dossier `include/` de `MeteoHub`.

---

## 2. Initialisation ESP-NOW sur l'ESP32-S3 (Récepteur)

Dans l'ESP32-S3 de MeteoHub, initialiser ESP-NOW après la connexion Wi-Fi (ou après `WiFi.mode(WIFI_STA)`) :

```cpp
#include <esp_now.h>
#include "meteo_packet.h"

// Variable globale pour stocker la dernière mesure reçue
static MeteoPacket lastOutdoorMetrics;
static bool outdoorMetricsAvailable = false;
static uint32_t lastOutdoorPacketTime = 0;

// Callback appelé à chaque réception d'une trame ESP-NOW
void onMeteoDataReceived(const uint8_t *mac, const uint8_t *incomingData, int len) {
    if (len != sizeof(MeteoPacket)) {
        Serial.printf("[METEO-S3] [WARN] Paquet de taille invalide: %d (attendu: %d)\n", len, sizeof(MeteoPacket));
        return;
    }

    MeteoPacket packet;
    memcpy(&packet, incomingData, sizeof(MeteoPacket));

    // 1. Validation de l'en-tête Magic
    if (packet.magic[0] != METEO_PACKET_MAGIC_0 || packet.magic[1] != METEO_PACKET_MAGIC_1) {
        Serial.println("[METEO-S3] [WARN] Magic packet invalide");
        return;
    }

    // 2. Validation du CRC16
    size_t dataLen = sizeof(MeteoPacket) - sizeof(packet.crc16);
    uint16_t expectedCrc = calculateCrc16((const uint8_t*)&packet, dataLen);
    if (packet.crc16 != expectedCrc) {
        Serial.println("[METEO-S3] [WARN] Echec de verification CRC16");
        return;
    }

    // 3. Traitement des métriques
    lastOutdoorMetrics = packet;
    outdoorMetricsAvailable = true;
    lastOutdoorPacketTime = millis();

    Serial.printf("[METEO-S3] Reception Sonde #%u (Seq: %u) : Temp=%.2f C, Hum=%.2f %%, Bat=%.2f V\n",
                  packet.node_id, packet.sequence, packet.temperature, packet.humidity, packet.battery_voltage);

    // 4. Injection dans le gestionnaire de stockage SD / historique de MeteoHub
    // sensorManager.updateOutdoorData(packet.temperature, packet.humidity, packet.pressure);
}

void initMeteoHubReceiver() {
    // Initialise ESP-NOW
    if (esp_now_init() == ESP_OK) {
        esp_now_register_recv_cb(onMeteoDataReceived);
        Serial.println("[METEO-S3] Recepteur ESP-NOW initialise avec succes");
    } else {
        Serial.println("[METEO-S3] [ERROR] Echec init ESP-NOW sur S3");
    }
}
```

---

## 3. Détection des pertes de paquets

Grâce au champ `packet.sequence` incrémenté à chaque émission par la sonde, MeteoHub peut détecter facilement les paquets perdus :

```cpp
static uint32_t expectedSequence = 0;

if (expectedSequence != 0 && packet.sequence > expectedSequence) {
    uint32_t lostCount = packet.sequence - expectedSequence;
    Serial.printf("[METEO-S3] [WARN] %u paquet(s) perdu(s) entre la sonde et le Hub\n", lostCount);
}
expectedSequence = packet.sequence + 1;
```

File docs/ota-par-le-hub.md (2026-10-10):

# Mise a jour OTA de la sonde par le hub

Objectif : ne plus rentrer la sonde pour chaque version pendant la phase de developpement.

## Principe

ESP-NOW ne transporte que 250 octets par trame : le binaire ne passe pas par la. Le hub ne fait que
proposer, la sonde va chercher.

1. Un binaire de sonde est depose sur le hub (page Systeme, carte « Firmware de la sonde »). Le hub le garde sur sa
   carte SD et lit la version dans la balise `MHSFW=` embarquee par le firmware : rien a saisir.
2. A chaque cycle, la sonde emet sa trame et declare sa version (`fw_version`).
3. Si la version du hub diffère, la reponse `SyncControl` du hub porte le drapeau `SYNC_FLAG_OTA_OFFER`
   (bit 15 de `want_count`) et une trame `OtaOffer` suit (version, taille, MD5).
4. En fin de cycle (mesure deja stockee, envoyee, accusee), la sonde s'associe au SoftAP `MH-NOW` du hub, telecharge
   `http://<passerelle>/sensor-fw.bin`, verifie le MD5, flashe le slot OTA inactif puis redemarre.

Aucun identifiant Wi-Fi de la box n'intervient : seul le mot de passe du SoftAP du hub (constante partagee) est utilise.

## Premier flash

La premiere version capable d'OTA se flashe en USB. Le hub refuse un binaire sans balise `MHSFW=` (anterieur a la
0.33.1). Les suivantes se deposent sur le hub.

## Garde-fous

- Pas de mise a jour sous 3,5 V si la batterie est mesuree.
- 5 tentatives au maximum par version proposee (compteur en memoire RTC, remis a zero par un power-cycle).
- Taille plafonnee a la partition d'application (1,25 Mo).
- Un echec laisse le firmware courant intact ; la sonde retente au reveil suivant.

## Limites

- Pas de retour arriere automatique : un firmware qui demarre mais ne parle plus au hub exige un reflash USB.
- L'offre n'est pas authentifiee (meme niveau de confiance que la liaison ESP-NOW, non chiffree).
- Le hub a besoin de sa carte SD pour stocker le binaire (sa LittleFS est trop petite).
- Le hub efface le binaire de lui-meme des que la sonde declare la version stockee. Pour annuler une offre en
  attente, le retirer depuis la page Systeme.
- Non teste sur materiel au moment de l'ecriture : compilation et tests hote seulement.

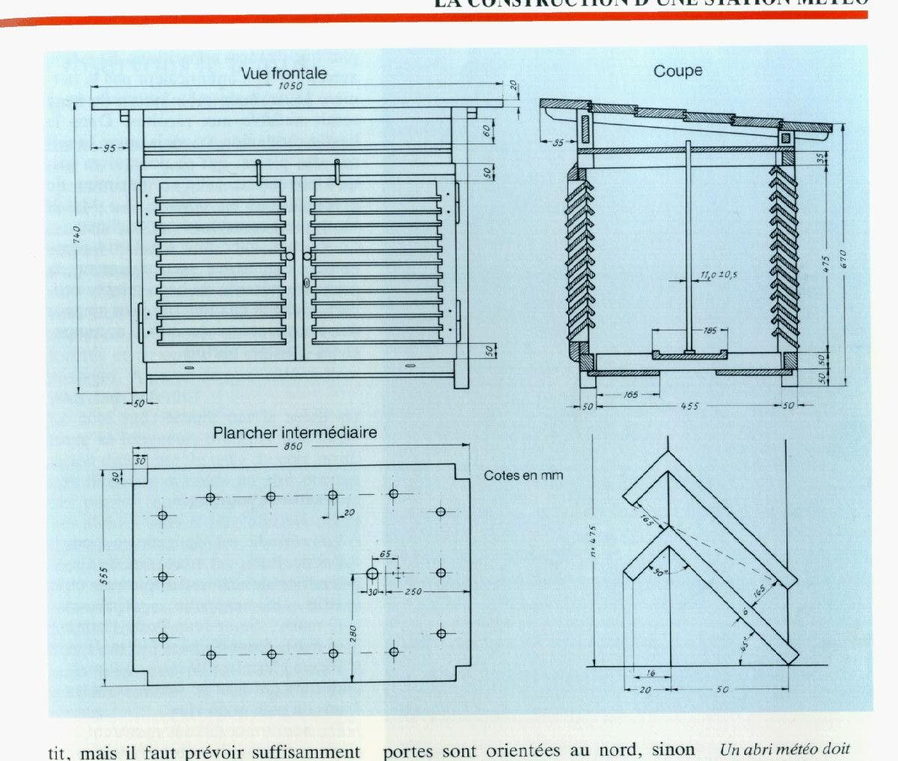
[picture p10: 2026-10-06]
enclosure/stevenson-reference-plan.jpg

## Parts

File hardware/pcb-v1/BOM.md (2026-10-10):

# Liste des composants - carte v1 de MeteoHubSensor

Liste tirée du schéma (`meteohubsensor-v1.kicad_sch`). Toutes les pièces de la carte sont traversantes : aucune
soudure CMS, **52 pastilles à souder** au total. Aucune référence de fournisseur (LCSC, Mouser...) n'est donnée :
elles n'ont pas été vérifiées.

## 1. Soudé sur la carte

### Résistances (3)

| Réf. | Qté | Valeur | Détail | Rôle |
| :--- | :-: | :--- | :--- | :--- |
| R1, R2 | 2 | 100 kohm | Axiale 1/4 W, tolérance **1 %** conseillée, boîtier DIN0207 | Pont de mesure de l'accu (GP4) |
| R3 | 1 | 10 kohm | Axiale 1/4 W, boîtier DIN0207 | Rappel du DHT22 (omettre avec un module 3 broches qui l'embarque) |

### Condensateurs (3)

| Réf. | Qté | Valeur | Détail | Rôle |
| :--- | :-: | :--- | :--- | :--- |
| C1 | 1 | 100 nF | Céramique disque, 50 V, pas 2,5 mm | Découplage près des broches 3V3/GND du S3 |
| C3 | 1 | 100 nF | Céramique disque, 50 V, pas 2,5 mm | Filtre du noeud ADC (GP4) |
| C2 | 1 | 220 uF | Électrolytique radial, **10 V ou plus**, diamètre 6,3 mm, pas 2,5 mm | Réserve de courant pour les pointes d'émission |

### Embases JST-XH (6 embases, 18 broches), pas 2,50 mm, verticales

| Réf. | Nom | Broches | Référence JST | Brochage (1 à n) |
| :--- | :--- | :-: | :--- | :--- |
| J1 | BAT | 2 | B2B-XH-A | + accu, - accu |
| J2 | BMP280 | 4 | B4B-XH-A | 3V3, SCL, SDA, GND |
| J3 | DHT22 | 3 | B3B-XH-A | 3V3, DATA, GND |
| J4 | ANEMO | 3 | B3B-XH-A | 3V3, impulsion, GND |
| J5 | PLUVIO | 3 | B3B-XH-A | 3V3, impulsion, GND |
| J6 | GIROUETTE | 3 | B3B-XH-A | 3V3, ADC, GND |

Récapitulatif : 1 x 2 broches, 4 x 3 broches (12 broches), 1 x 4 broches, soit 2 + 12 + 4 = 18 broches.

### Supports et module

| Réf. | Qté | Pièce | Détail |
| :--- | :-: | :--- | :--- |
| U1 | 2 | Barrette femelle 1x9, pas 2,54 mm | Une par rangée du S3 (18 broches au total), entraxe des rangées 15,24 mm |
| U2 | 1 | Module abaisseur 3,3 V (Youmi, SOT-223) | 4 broches mâles soudées : deux paires espacées de 22,86 mm, circuit 25,6 x 11,3 mm |

Trous de fixation H1 à H4 : 4 trous M3 (3,2 mm), aucune pièce sur la carte.

## 2. À fournir, non soudé sur la carte

| Qté | Pièce | Remarque |
| :-: | :--- | :--- |
| 1 | ESP32-S3 Super Mini N4R2 | Se pose sur les supports U1, USB-C vers l'intérieur de la carte |
| 1 | Module BMP280 (avec ou sans AHT20) | Seule la pression est lue |
| 1 | DHT22 (ou module 3 broches) | Température et humidité de référence |
| 1 | Accu Li-ion 3,7 V | 3000 mAh en place ; chargé hors de la sonde, sans protection sur cette carte |
| 1 | Anémomètre, 1 pluviomètre, 1 girouette | Futurs ; seuls les connecteurs J4, J5, J6 sont prévus |
| 1 | Boîtier femelle JST-XHP 2 broches | Pour J1 |
| 4 | Boîtiers femelles JST-XHP 3 broches | Pour J3, J4, J5, J6 |
| 1 | Boîtier femelle JST-XHP 4 broches | Pour J2 |
| 18 | Cosses à sertir JST-XH (SXH) | 2 + 12 + 4, prévoir quelques cosses de plus pour les ratés de sertissage |
| - | Fil souple 22 à 26 AWG | Pour les câbles des capteurs et de l'accu |
| 4 | Vis M3 et entretoises | Pour la fixation, si le boîtier en demande |

## 3. Totaux

| Famille | Pièces | Pastilles à souder |
| :--- | :-: | :-: |
| Résistances | 3 | 6 |
| Condensateurs | 3 | 6 |
| Embases JST-XH | 6 | 18 |
| Barrettes femelles 1x9 | 2 | 18 |
| Module régulateur | 1 | 4 |
| **Total** | **15** | **52** |

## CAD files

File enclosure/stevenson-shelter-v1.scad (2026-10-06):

//
// ============================================================================
// MeteoHubSensor - MINI ÉCRAN DE STEVENSON
// V8 - adaptation du plan Stevenson traditionnel fourni
// ============================================================================
//
// Référence de conception :
// le plan traditionnel montre des lames inclinées vers l'extérieur,
// superposées sur les quatre faces, avec une vraie circulation d'air.
// Cette version reprend CE principe, à l'échelle du MeteoHubSensor.
//
// DIMENSIONS
// ----------
// Volume intérieur : 110 x 90 x 110 mm
// Caisson extérieur : 130 x 110 x 130 mm
//
// LAMELLES
// --------
// 10 par face
// section : 110 x 8 x 4 mm
// inclinaison : 40° sous l'horizontale
// pas vertical : 11.2 mm
// ouverture verticale projetée : ~2.5 mm
//
// IMPORTANT :
// "extérieur plus bas" est garanti sur les quatre faces.
//
// AVANT  : extérieur = Y-  -> +40°
// ARRIÈRE: extérieur = Y+  -> -40°
// GAUCHE : extérieur = X-  -> -40°
// DROITE : extérieur = X+  -> +40°
//
// Le choix de 40° est volontairement proche du profil visible sur
// la coupe du plan traditionnel fourni.
// ============================================================================

$fn = 48;

// ---------------------------------------------------------------------------
// CAISSON
// ---------------------------------------------------------------------------

IW = 110;
ID = 90;
IH = 110;

POST = 10;
POST_H = 130;

// ---------------------------------------------------------------------------
// LAMELLES
// ---------------------------------------------------------------------------

SLAT_L     = 110;
SLAT_T     = 4;
SLAT_H     = 8;

SLAT_COUNT = 10;
SLAT_PITCH = 11.2;

// Centre de la première lame.
// Les 10 lames couvrent pratiquement toute la hauteur intérieure.
SLAT_Z0 = 4.8;

SLAT_ANGLE = 40;

// ---------------------------------------------------------------------------
// TOIT DOUBLE - inspiré du principe du plan traditionnel
// ---------------------------------------------------------------------------

ROOF_W   = 160;
ROOF_D   = 140;
ROOF_T   = 5;
ROOF_GAP = 12;

// ---------------------------------------------------------------------------
// ÉLECTRONIQUE V1
// ---------------------------------------------------------------------------

SHOW_ELECTRONICS = true;

BOARD_X = 90;
BOARD_Y = 50;
BOARD_T = 1.6;

BAT_X = 90;
BAT_Y = 22;
BAT_T = 12;

RECT_X = 25;
RECT_Y = 10;
RECT_T = 8;

// ---------------------------------------------------------------------------
// COULEURS
// ---------------------------------------------------------------------------

wood        = [0.72,0.50,0.28];
wood_slat   = [0.82,0.62,0.38];
electronics = [0.15,0.18,0.20];
battery_col = [0.25,0.25,0.25];
rectifier_col = [0.10,0.35,0.10];
sensor_col  = [0.75,0.75,0.75];


// ============================================================================
// MONTANTS
// ============================================================================

module post(x,y) {
    color(wood)
        translate([x,y,0])
            cube([POST,POST,POST_H]);
}


// ============================================================================
// LAMELLES
//
// Chaque lame est centrée sur z puis inclinée.
//
// Le bord extérieur est toujours plus bas :
//
//                 INTÉRIEUR
//                     ▲
//                     │
//             ───────────────
//                ╲
//                 ╲
//                  ╲
//             ───────────────
//                     │
//                     ▼
//                 EXTÉRIEUR
//
// Le vide entre deux lames est réel : l'air peut entrer/sortir.
// ============================================================================

// AVANT : extérieur Y-
module slat_front(z) {
    color(wood_slat)
        translate([POST, POST, z])
            rotate([+SLAT_ANGLE,0,0])
                translate([0,-SLAT_T/2,-SLAT_H/2])
                    cube([SLAT_L,SLAT_T,SLAT_H]);
}

// ARRIÈRE : extérieur Y+
module slat_back(z) {
    color(wood_slat)
        translate([POST, ID+POST, z])
            rotate([-SLAT_ANGLE,0,0])
                translate([0,-SLAT_T/2,-SLAT_H/2])
                    cube([SLAT_L,SLAT_T,SLAT_H]);
}

// GAUCHE : extérieur X-
module slat_left(z) {
    color(wood_slat)
        translate([POST,POST,z])
            rotate([0,-SLAT_ANGLE,0])
                translate([-SLAT_T/2,0,-SLAT_H/2])
                    cube([SLAT_T,SLAT_L,SLAT_H]);
}

// DROITE : extérieur X+
module slat_right(z) {
    color(wood_slat)
        translate([IW+POST,POST,z])
            rotate([0,+SLAT_ANGLE,0])
                translate([-SLAT_T/2,0,-SLAT_H/2])
                    cube([SLAT_T,SLAT_L,SLAT_H]);
}


// ============================================================================
// CADRE INFÉRIEUR
//
// Le plan traditionnel possède un plancher intermédiaire.
// Pour MeteoHubSensor, on ne ferme pas le dessous : la sonde doit rester
// ventilée et l'électronique ne doit pas créer une poche thermique.
// On conserve uniquement un cadre porteur.
// ============================================================================

module lower_frame() {
    color(wood);

    // traverse avant
    translate([0,0,0])
        cube([IW+2*POST,POST,POST]);

    // traverse arrière
    translate([0,ID+POST,0])
        cube([IW+2*POST,POST,POST]);

    // traverses latérales
    translate([0,POST,0])
        cube([POST,ID,POST]);

    translate([IW+POST,POST,0])
        cube([POST,ID,POST]);
}


// ============================================================================
// DOUBLE TOIT
// ============================================================================

module roof_plate(z) {
    color(wood)
        translate([
            (IW+2*POST-ROOF_W)/2,
            (ID+2*POST-ROOF_D)/2,
            z
        ])
            cube([ROOF_W,ROOF_D,ROOF_T]);
}

module roof_spacer(x,y,z) {
    color(wood)
        translate([x,y,z])
            cube([POST,POST,ROOF_GAP]);
}


// ============================================================================
// ÉLECTRONIQUE V1 - SIMPLE ENCOMBREMENT
// ============================================================================

module board_demo() {

    // Carte actuelle 90 x 50 mm
    color(electronics)
        translate([POST+10, POST+ID-5, 18])
            rotate([90,0,0])
                cube([BOARD_X,BOARD_Y,BOARD_T]);

    // Support batterie 90 x 22 mm
    color(battery_col)
        translate([POST+10, POST+ID-8, 22])
            rotate([90,0,0])
                cube([BAT_X,BAT_Y,BAT_T]);

    // Petit redresseur 25 x 10 mm
    color(rectifier_col)
        translate([POST+15, POST+ID-10, 76])
            rotate([90,0,0])
                cube([RECT_X,RECT_Y,RECT_T]);
}


// ============================================================================
// CAPTEUR DÉPORTÉ
// ============================================================================

module sensor_demo() {

    // Position haute et centrale
    color(sensor_col)
        translate([
            POST+IW/2,
            POST+ID/2,
            94
        ])
            rotate([0,90,0])
                cylinder(d=16,h=12,center=true);

    // Faisceau indicatif
    color([0.08,0.08,0.08])
        translate([
            POST+IW/2,
            POST+ID/2,
            38
        ])
            cylinder(d=3,h=56);
}


// ============================================================================
// ABRI COMPLET
// ============================================================================

module shelter() {

    // 4 montants
    post(0,0);
    post(IW+POST,0);
    post(0,ID+POST);
    post(IW+POST,ID+POST);

    // Cadre inférieur ouvert
    lower_frame();

    // Lamelles Stevenson : 10 rangées sur chacune des 4 faces
    for (i=[0:SLAT_COUNT-1]) {

        z = SLAT_Z0 + i*SLAT_PITCH;

        slat_front(z);
        slat_back(z);
        slat_left(z);
        slat_right(z);
    }

    // Toit double : 12 mm de lame d'air
    roof_plate(POST_H);

    for (x=[0,IW+POST])
        for (y=[0,ID+POST])
            roof_spacer(x,y,POST_H+ROOF_T);

    roof_plate(POST_H+ROOF_T+ROOF_GAP);

    if (SHOW_ELECTRONICS)
        board_demo();

    sensor_demo();
}

shelter();
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

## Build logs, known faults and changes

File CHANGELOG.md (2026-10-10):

# Changelog

All notable changes to this project will be documented in this file.

The format is based on [Keep a Changelog](https://keepachangelog.com/en/1.0.0/),
and this project adheres to [Semantic Versioning](https://semver.org/spec/v2.0.0.html).

## [0.33.2] - 2026-10-10

- Version bump only: build used to test the OTA update end to end (probe on 0.33.0/0.33.1, binary uploaded to the hub).

## [0.33.1] - 2026-10-10

### Changed

- The firmware embeds an `MHSFW=<version>` tag. The hub reads the version from the uploaded binary, so nobody has to
  type it (a wrong label could no longer cause update loops). Binaries older than 0.33.1 are refused by the hub.

## [0.33.0] - 2026-10-10

### Added

- **OTA update driven by the hub.** When the hub holds a sensor firmware whose version differs from the one the probe
  reports, its `SyncControl` reply carries `SYNC_FLAG_OTA_OFFER` (bit 15 of `want_count`, ignored by older firmware)
  and an `OtaOffer` frame follows (version, size, MD5). At the end of the cycle, once the measurement is stored, sent
  and acknowledged, the probe joins the hub SoftAP `MH-NOW` (no home Wi-Fi credentials involved), downloads
  `/sensor-fw.bin` over HTTP and flashes the idle OTA slot. The MD5 is verified by `Update.end()`; on any failure the
  running image is kept. Nothing changes on a normal wake-up: the wait for an offer only happens when the flag is set.
- Safeguards (`include/ota/ota_logic.h`, host-tested): no update below 3.5 V when the battery is measured, at most 5
  attempts per offered version (kept in RTC memory), image size capped to the app partition.
- `docs/ota-par-le-hub.md`: how it works, first USB flash, limits.

### Fixed

- `ESPNOW_HUB_AP_PASS` now matches the hub SoftAP password (it held a stale value, unused until now).

### Notes

- The first OTA-capable build must still be flashed over USB. No automatic rollback (the core ships without app
  rollback): a firmware that boots but cannot talk to the hub needs a USB reflash.
- The offer is not authenticated (same trust level as the unencrypted ESP-NOW link).

## [0.32.14] - 2026-10-09

- `hardware/pcb-v1/`: generate the fabrication files (Gerber for both copper layers, masks, silkscreen and outline,
  Excellon drill files split into plated and non-plated) with `kicad-cli`, packed in `meteohubsensor-v1-gerber.zip`.
  Generated files are kept out of git (`fabrication/` ignored); they are rebuilt from the PCB.

## [0.32.13] - 2026-10-09

- `hardware/pcb-v1/BOM.md`: detailed bill of materials (values, quantities, JST-XH pin counts and pinouts, housings and
  crimp contacts to supply, 52 solder pads in total). No supplier part numbers.

## [0.32.12] - 2026-10-09

- `hardware/pcb-v1/`: add the missing silkscreen labels "DHT22" (J3) and "GIROUETTE" (J6). DRC and ERC clean.

## [0.32.11] - 2026-10-09

- `hardware/pcb-v1/`: J2 (BMP280) is now 3V3, SCL, SDA, GND: same logic as the other connectors (+, signals, GND), 3V3 and
  GND no longer neighbours, and SCL / SDA reach their GPIOs without crossing, so the back-layer hop is gone.
- The stitching via near J2 is removed: DRC no longer reports any isolated copper without it.
- DRC and ERC clean (schematic parity OK).

## [0.32.10] - 2026-10-09

- `hardware/pcb-v1/`: regulator module re-oriented so that, seen from above with the pins down, VIN and VOUT are on the
  lower pin of each pair and GND on the upper pin (VIN on the left, VOUT on the right). VBAT and 3V3 tracks re-routed.
- J2 (BMP280) now follows the usual I2C connector order GND, 3V3, SDA, SCL (Qwiic / STEMMA QT), with a short back-layer
  hop for SDA. Other connectors unchanged: J1 + / -, J3 to J6 3V3, signal, GND (DHT22 / AM2302 datasheet order).
- README documents every connector pinout. DRC and ERC clean (schematic parity OK).

## [0.32.9] - 2026-10-09

- `hardware/pcb-v1/`: regulator module pin pairs back to 22.86 mm centre to centre (9 pitches). The 0.32.8 value
  (22.16 mm) came from reading the measured 22.8 mm as an overall dimension; standard 0.64 mm pins that fit a
  breadboard sit on the 2.54 mm grid, so 22.8 mm was the centre distance. Board outline 25.6 x 11.3 mm kept.
  DRC and ERC clean.

## [0.32.8] - 2026-10-09

- `hardware/pcb-v1/`: regulator module footprint updated from measurements: 25.6 x 11.3 mm board, pin pairs 22.16 mm
  apart centre to centre (22.8 mm overall), 2.54 mm pitch inside each pair; outline and 3D model follow. ESP32-S3
  socket spacing confirmed (15.9 mm overall = 15.24 mm centre to centre). DRC and ERC still clean.

## [0.32.7] - 2026-10-09

- Add `hardware/pcb-v1/BOM.md`: bill of materials of the v1 board (through-hole parts only) plus the parts to supply
  separately (module, sensors, battery, JST housings). No supplier part numbers, none was checked.

## [0.32.6] - 2026-10-09

- `hardware/pcb-v1/`: make every identifier in the generated schematic and PCB deterministic, and pin the root sheet
  identifier to the one already stored in the `.kicad_pro`. Before, each regeneration produced new identifiers, so a
  `.kicad_pro` kept from an earlier delivery no longer matched the schematic (different root sheet UUID), which is a
  suspect for the two schematic parity warnings seen in the KiCad editor (J1 pin 2, U2 VOUT). `kicad-cli` never
  reproduced them.
- Ignore exported ERC/DRC reports (`*.rpt`) in the board folder.

## [0.32.5] - 2026-10-09

- `hardware/pcb-v1/`: remove the explicit GND tracks added in 0.32.4 (and the four ground vias that went with them).
  They cluttered the drawing for no benefit: the ground pours on both layers and the through-hole pads already connect
  every GND pin. The single stitching via near J2 stays.
- DRC clean (0 error, 0 unconnected, schematic parity OK), ERC clean.

## [0.32.4] - 2026-10-09

- `hardware/pcb-v1/`: add explicit GND tracks on the front layer (0.4 mm, tree from the ESP32-S3 GND pad) on top of the
  ground pours, so the ground path is visible. Four pads enclosed by signal tracks (J3, J4, J5, J6) get a short track
  to a ground via. Same net as the pours, so nothing changes for fabrication.
- DRC clean (0 error, 0 unconnected, schematic parity OK), ERC clean.

## [0.32.3] - 2026-10-09

- `hardware/pcb-v1/`: the board is now centered on the A4 drawing sheet (outline from 115.5 / 80 to 181.5 / 130 mm).
  Layout and connections are unchanged; DRC and ERC still clean.

## [0.32.2] - 2026-10-09

- `hardware/pcb-v1/`: ground (GND) is now poured on both layers (it was back layer only, so the top side showed
  no ground copper), with one stitching via near J2. The antenna keep-out still clears both layers.
- Add simplified 3D models for the ESP32-S3 sockets and module and for the 3.3 V regulator module, so both appear
  in the 3D viewer.
- ERC clean, DRC clean (schematic parity OK) with `kicad-cli` 10.0.7.

## [0.32.1] - 2026-10-09

- `hardware/pcb-v1/`: the ESP32-S3 socket pads and schematic pins now carry the labels printed on the module
  (TX, RX, 1..7 on the left; 5V, GND, 3V3, 13..8 on the right) instead of 1..18, so pad 8 is GPIO8 (SDA) and
  pad 9 is GPIO9 (SCL). Pin names show the function in this project. Same electrical connections as 0.32.0.
- Add J6 (wind vane, JST-XH: 3V3, signal, GND) on GP2, with a short back-layer hop to cross the DHT22 track.
- ERC and DRC (with schematic parity) still clean with `kicad-cli` 10.0.7.

## [0.32.0] - 2026-10-09

- Add `hardware/pcb-v1/`: KiCad 10 project (schematic, routed 2-layer PCB 66 x 50 mm, project symbol and
  footprint library) for the v1 board. ESP32-S3 Super Mini on two female 1x9 sockets (swappable without
  desoldering), 3.3 V regulator module, 100 k / 100 k battery divider on GP4 with a 100 nF filter, 100 nF + 220 uF
  at the module supply pins, JST-XH connectors for battery, BMP280 (GP8/GP9), DHT22 (GP1), anemometer (GP5) and
  rain gauge (GP7), pinout unchanged from `board_config.h`.
- The module is placed USB side inward so the ceramic antenna sits on the board edge, with a copper keep-out
  (tracks, vias, ground pour, both layers) under and behind it.
- ERC clean, DRC clean (0 error, 0 unconnected, schematic parity OK) with `kicad-cli` 10.0.7. Socket row spacing,
  regulator pin spacing and connector polarity are flagged in the README as to be measured before fabrication.
- Docs: `hardware/pcb-v1/README.md`, `docs/cablage.md` section 5.

## [0.31.0] - 2026-10-08

- The DHT22 is now the reference for both temperature and humidity. The BMP280+AHT20 module is only
  used for atmospheric pressure: the AHT20 is no longer read (`Adafruit AHTX0` dependency removed, `hasAht()`
  dropped) and there is no fallback any more. If the DHT22 is silent or returns an invalid frame, temperature
  and humidity are left out of the packet (validity bits at 0).
- Reason: the DHT22 reading is better, more stable and more realistic than the AHT20 of the module. Its
  humidity was calibrated against a saturated salt (NaCl) solution, which naturally gives 75 % RH: the probe
  returned 75.0 to 75.1 % for 2 hours, so it is considered stable and well calibrated.
- Add `DHT22_HUM_OFFSET` and `DHT22_TEMP_OFFSET` (both 0) in `board_config.h` for a future recalibration.
- Docs: `docs/notes.md` section 6, `docs/cablage.md`, both READMEs.

## [0.30.2] - 2026-10-08

- Document why the DHT22 has priority for humidity: in the real installation it is better isolated than
  the AHT20/BMP280 module, gives a more realistic reading and does not stick at 100 %. Note the v3 layout
  idea (S3 reversed so the antenna sits at the board edge, untested). Documentation only, no firmware
  change.

## [0.30.1] - 2026-10-07

- Document the field results: 0.30.0 runs in production on the v1 board (humidity from the DHT22 is
  transparent for the hub), and the v2 board sends no frame to the hub with or without the wire antenna
  (hypothesis: radio interference from the wiring under the board; removing the S3 from the board
  does not help, the antenna area cannot be cleared without defeating the purpose of the v2, a smaller
  board, and it fails even next to the hub, so the v2 is dropped). `docs/notes.md` section 7 and
  `docs/cablage.md` updated. Documentation only, no firmware change.

## [0.30.0] - 2026-10-07

- Add a DHT22 humidity sensor on GPIO1 (DATA, 3V3, GND). Humidity comes from the DHT22 first; if it
  is absent or returns an invalid frame, it falls back to the AHT20 of the BMP280+AHT20 module. The
  temperature still comes from the AHT20 (DHT22 temperature only if the AHT20 is silent).
- Move the anemometer reserve pin from GPIO1 to GPIO5 (`PIN_ANEMOMETER_PULSE`); `PIN_FREE_GP5` removed.
- New dependency: `adafruit/DHT sensor library`. Validated on the bench (`dht22-aht-compare`): temperatures within 0.2 degC, humidity DHT22 about 2 points below AHT20.

## [0.29.15] - 2026-10-07

- Note the envisaged v3 board in `docs/cablage.md`: small solar panel and solar charger coupled to a
  protected battery, to remove the manual cell swap. Nothing defined yet. Documentation only.

## [0.29.14] - 2026-10-07

- Document the power chain precisely in `docs/cablage.md`: the regulator is a Youmi "3.3 V DC/DC
  step-down" module (advertised input 4.5-7 V, 3.3 V out, 800 mA); the cell is charged outside the
  sensor in a desk charger (no USB charging in this version), with two cells swapped when needed;
  the 0 % threshold at 2.6 V is confirmed. Add a measurement warning: the advertised input range is
  above a Li-ion cell's range, so the 3.3 V rail may sag before the cell is empty. `notes.md` and the
  `board_config.h` comment aligned. Documentation and comments only, no firmware change.

## [0.29.13] - 2026-10-07

- Align the last stale wording: the `config.h` comment no longer names the old 14500 cell (the
  battery is now a 3000 mAh Li-ion). Remaining Breadvolt mentions are historical or flagged
  "to confirm" in `docs/cablage.md`. Comment only, no firmware change.

## [0.29.12] - 2026-10-07

- Document the regulator wiring in `docs/cablage.md`: the cell is connected to VIN and GND of the
  regulator module, which supplies 3.3 V (VOUT) and ground (GND) to the board; same on v1 and v2.
  Documentation only, no firmware change.

## [0.29.11] - 2026-10-07

- Fix the v1 board description in `docs/cablage.md`: the four 2-pin Dupont sockets hosted the
  Breadvolt (now removed); the 3.3 V regulator module is not plugged on them, its output goes to the
  JST next to those sockets, on the power rail. Documentation only, no firmware change.

## [0.29.10] - 2026-10-07

- Add `enclosure/`: first version of a mini Stevenson screen for the sensor (OpenSCAD model
  `stevenson-shelter-v1.scad`, 3D-printable, louvres tilted 40 degrees on four faces) and the
  traditional reference plan it is adapted from. Files renamed to kebab-case, em dashes removed
  from the model header. Not printed or tested yet. No firmware change.

## [0.29.9] - 2026-10-07

- Document the v1 (production, uPesy) and v2 (bench, Electrocookie) boards in a new section 5 of
  `docs/cablage.md`, with photos: same three JST on both, 3.3 V regulator module plugged on four
  2-pin Dupont sockets on v1 and soldered on v2, wire antenna on the v1 S3 only for now (it will
  move to v2).
- Correct the power documentation: the Breadvolt module is no longer on the production board, it
  was replaced by a 3.3 V regulator module (same on v1 and v2). README, `docs/notes.md` and the
  `board_config.h` comments are aligned; the missing charge/protection and dropout details are
  flagged "to confirm" in `docs/cablage.md`.
  Documentation and comments only, no firmware change.

## [0.29.8] - 2026-10-06

- Refine the wire-antenna notes in `docs/notes.md`: describe the wire as added around the ceramic
  antenna (not soldered onto the chip), clarify that 35 mm is not exactly a quarter wave, state that
  the bench shows a better RSSI but not yet a measurable reliability gain (loss was already 0 %),
  make the subjective Wi-Fi impression impersonal, and keep the story of how the idea came about.
  Documentation only, no firmware change.

## [0.29.7] - 2026-10-06

- Document the wire-antenna build (20 AWG solid wire, 35 mm, 15 mm vertical, loop around both sides
  of the ceramic antenna) and its sources (espboards.dev note, Hackaday article) in `docs/notes.md`.
  Documentation only, no firmware change.

## [0.29.6] - 2026-10-06

### Documentation

- Add the photo of the wire-antenna mounting (`docs/antenne-filaire-g2.jpg`) and embed it in
  `docs/notes.md`, so the field note no longer depends on a scratch project.

## [0.29.5] - 2026-10-06

### Documentation

- Clarify in `docs/notes.md` that the "C3" printed on the red ceramic chip is the antenna marking,
  shared by the ESP32-C3 and ESP32-S3 Super Mini boards, not the SoC.

## [0.29.4] - 2026-10-06

### Documentation

- Field note on the wire-antenna test (`docs/notes.md`, section 5): old and new prod probe are
  the same board model (ESP32-S3 Super Mini N4R2), hub reference RSSI -37 dBm over 107/107
  frames, antenna geometry and bench results. No code change.

## [0.29.3] - 2026-10-05

### Added

- **Full link re-association after repeated no-ACK cycles.** Field case (2026-10-05): the hub kept
  its channel and uptime, the sensor kept measuring and buffering, yet live frames got no ACK for
  10 to 15 minutes; only a radio re-initialisation (re-scan wake or re-pairing) cleared it. The
  in-send re-scan found the same channel and gave up. Now a counter of consecutive failed LIVE
  cycles (kept in RTC memory, survives deep sleep) triggers, from the 3rd failed cycle
  (`ESPNOW_REASSOCIATE_AFTER_FAILS`), a full re-association: ESP-NOW stopped, Wi-Fi radio cycled,
  channel re-scanned, ESP-NOW and hub peer set up again, then one more send. A single missed ACK
  changes nothing (the hub claims the missing measurement next cycle). No extra cost in normal
  operation; during an outage the re-scan was already done on every no-ACK.

### Changed

- `EspNowSender`: radio and ESP-NOW setup factored into `startRadio()` / `initEspNow()`, shared by
  `begin()` and `reassociate()`.

## [0.29.2] - 2026-10-03

### Changed

- **Build environment renamed `esp32-s3-supermini` -> `sonde-supermini`** (the hub now uses
  `hub-supermini`): one distinct name per project, so the wrong board cannot be flashed by
  picking the default environment. Build with `pio run -e sonde-supermini`. `morfproject.json`
  `env` follows; the target key `esp32s3-supermini` is unchanged (release asset names stay).
- README (en/fr), `cablage.md` and header comments updated.

## [0.29.1] - 2026-10-03

### Changed

- `BATTERY_VREF_CALIBRATION` 1.0515 -> **1.036**, from two multimeter/probe readings on the
  3000 mAh cell (3.927 V vs 3.98 V reported, 4.074 V vs 4.14 V reported; real factors 1.0377
  and 1.0347). The first reading (1.0515) was taken with the old firmware right after charging
  and is discarded. Residual with 1.036: -0.2 % / +0.1 %. Re-check at a stable full charge
  (~4.2 V) and at mid charge. Needs a reflash of the probe.

## [0.29.0] - 2026-10-03

### Changed

- **Battery voltage calibrated for the new Li-ion 3.7 V 3000 mAh cell**: `BATTERY_VREF_CALIBRATION`
  1.0 -> 1.0515 (3.859 V on the multimeter vs 3.67 V reported; the 100k/100k divider's 50 kohm
  source impedance makes the S3 ADC read low, proportionally). One measuring point only: re-check at a
  second charge level.
- **State of charge from a Li-ion discharge curve** (`include/battery_curve.h`, 21 points,
  interpolated) instead of a straight line 2.6-4.2 V, which showed 69 % at 3.7 V where ~15 % is
  left. The generic table is not measured on this cell. `BATTERY_VOLTAGE_MIN/MAX` now only bound
  the plausibility guard.

### Added

- Native unit test `test_native_battery` (bounds, reference points, monotonic curve).
- Needs a reflash of the probe to take effect.

## [0.28.3] - 2026-10-03

### Fixed

- Documentation only: the 1.x entry below blamed the registry for resolving an unpinned
  `espressif32` to a Tasmota fork. Wrong. The official registry (`platformio/espressif32`, tier
  "official") resolves it to 7.1.3 with the official core (checked). The switch to
  pioarduino/Tasmota happened through a PlatformIO core contaminated on 2026-10-01 (exact trigger
  not proven; a project pointing at a pioarduino URL is the likely candidate). The pin stays, for
  reproducibility.

## [0.28.2] - 2026-10-03

### Changed

- **PlatformIO platform pinned to the official `espressif32@7.1.3`** (Arduino core 2.0.17).
  (Correction, see the next entry: an unpinned `espressif32` resolves to the official 7.1.3 with
  the official core; the pioarduino switch came from a PlatformIO core already contaminated.)
  There is no official core 3.x platform: staying official means core 2.x. The source keeps
  compiling on both cores (`ESP_ARDUINO_VERSION_MAJOR` guards).
- Build verified on 7.1.3: `esp32-s3-supermini` flash 61.8 %. No more Windows "CreateProcess" command-line overflow
  (the shorter `framework-arduinoespressif32` path of 7.1.x).
- Not reflashed: the devices currently run builds made on the Tasmota platform (core 3.x).

## [0.28.1] - 2026-10-03

### Changed

- `platformio.ini`: comment recording that the official PlatformIO platform is used and that
  pioarduino is deliberately NOT used (flash 95 % instead of 66 %, corrupted PlatformIO cache).

## [0.28.0] - 2026-10-03

### Changed

- **Migrated to the current PlatformIO platform (Arduino core 3.x / ESP-IDF 5).** The platform pin (`espressif32@6.12.0`, Arduino core 2.x) is removed: it made the compiler
  command line exceed the Windows limit (`g++: error: CreateProcess: No such file or directory`),
  independently of the code. The projects now build on the current platform (Arduino core 3.3.x /
  ESP-IDF 5), all ESP-NOW projects together.
- ESP-NOW send and receive callbacks adapted to the new signatures (`wifi_tx_info_t`,
  `esp_now_recv_info_t`), compatible with core 2.x behind `ESP_ARDUINO_VERSION_MAJOR`.
- Board constant `PIN_RGB_LED` renamed `PIN_LED_RGB`: core 3.x defines a macro of that name.
- Build verified for `esp32-s3-supermini` (flash 52 %). Not flashed nor tested on hardware
  yet: check pairing, ACK, deep sleep wake and battery reading on the bench first.

## [0.27.0] - 2026-09-29

### Added

- **The probe sends its firmware version.** Every data frame (live and retransmitted)
  carries `fw_version` from `PROJECT_VERSION` (data frame version 4, 67 bytes, shared
  `meteo_packet.h` identical to the hub's). MeteoHub 1.55.0 shows it on its dashboard.
  **Flash the hub first**: an older hub rejects v4 frames without acknowledging them,
  so the probe keeps them and resends them once the hub is updated (nothing lost).
  Pairing and control frames are unchanged (version 3).

## [0.26.0] - 2026-09-29

### Changed

- **Sensors are read before the radio starts.** One wake-up out of
  `ESPNOW_RESCAN_EVERY_N_WAKES` (12, about once an hour) rescans the hub channel
  (~2 s of radio at full power) inside `espNowSender.begin()`. The measurement taken
  afterwards suffered the board heating and current draw: an hourly pressure spike
  on 2026-09-29. `setup()` now reads the sensors right after `sensorManager.begin()`,
  radio off, and hands the reading to `performCycle()`: every wake-up measures in the
  same conditions. Battery voltage is still read under radio load (the hub's alert
  thresholds were set on that reference). Continuous / light-sleep modes, where the
  radio stays on, keep reading in `performCycle()`.

## [0.25.3] - 2026-09-28

### Changed

- **Build environment renamed `esp32-s3` -> `esp32-s3-supermini`**, the same name
  as in MeteoHub for the same board. Build with `pio run -e esp32-s3-supermini`.
  The packaging target in `morfproject.json` follows (`esp32s3-supermini`), so the
  release `.bin` asset name changes. Docs updated. No firmware behaviour change.

## [0.25.2] - 2026-09-28

### Fixed

- **AHT20 all-zero reading sent as a valid -50 degC / 0 % measurement.** A zeroed
  raw frame (wet sensor, disturbed I2C bus) converts to exactly -50 / 0 and the
  library reports it as valid. That exact signature is now rejected, so the packet
  leaves with the temperature/humidity flags cleared. Strict equality, not a
  threshold: no real winter reading is discarded (the AHT20 does not go below
  -40 degC).

## [0.25.1] - 2026-09-27

### Fixed

- **`README.md` was a French copy of `README.fr.md`.** It is now the English
  version; each README links to the other.
- **Leftovers of the removed C3 target.** `LICENSE` still called the project an
  "ESP32-C3 outdoor sensor node", and the shared `meteo_packet.h` named the sender
  an ESP32-C3 (same fix on the MeteoHub side, the file stays identical).

### Removed

- **The OLED display module (`DisplayManager`).** It only served the retired C3
  HW-675 board: `SENSOR_HAS_OLED` was never defined anymore, U8g2 was no longer in
  `lib_deps` (the module could not even build if enabled), and every call was a
  no-op. Its calls in `main.cpp` and the matching `board_config.h` notes are gone.

### Changed

- Em dashes replaced by `-` in the project's own files.

## [0.25.0] - 2026-09-27

### Changed

- **No default hub MAC: an unpaired probe sends nothing until it is paired.**
  `ESPNOW_RECEIVER_MAC` is now all zeros. It used to hold the production hub's
  STA MAC, so a probe whose flash was erased silently targeted that one hub.
  After swapping hubs (production board <-> bench board), an erased probe would
  have sent its measurements to the wrong hub, and a bench probe to the
  production history. Now an erased or new probe keeps its measurements pending
  in the local buffer and waits for a long press on BOOT. **Upgrade note:** a
  probe in service that was never paired (still relying on the old default)
  stops sending after this update until it is paired; nothing is lost, its
  measurements wait in the buffer.
- An unpaired probe no longer scans for the hub channel on each wake (~2 s of
  radio for nothing): pairing sweeps every channel by itself.

## [0.24.1] - 2026-09-26

### Changed

- **BMP280 set to Bosch's "weather monitoring" profile**: forced mode, x1
  oversampling for temperature and pressure, IIR filter OFF (was x2/x16 with an
  x16 IIR filter). With one measurement every 5 min, the x16 filter either
  smoothed pressure over more than an hour or restarted from scratch on a
  reboot, creating a step. The probe must report the sensor's real response;
  qualifying measurements belongs higher up the chain (hub, analytics), never
  in the probe. x1 oversampling is enough for the displayed 0.1 hPa and
  shortens the conversion (less awake time).

 - 2026-09-26

### Changed

- **The local buffer is now a segmented, append-only journal.** Measured on the
  bench probe: 4.5 s blocked on every measurement write, radio on. The 30-day
  buffer was a single 276 KB LittleFS file whose header, at offset 0, was
  rewritten on every measurement and every hub ack; LittleFS being copy-on-write,
  each flush copied the whole file. The new `SegmentStore`
  (`include/sync/segment_store.h`, pure and host-tested) stores one small file per
  day of measurements (`/mhs/<first_seq>.seg`, 288 x 32 B) written by append only;
  the ack watermark and the drop counter live in NVS; fully acknowledged segments
  are deleted (the last one is kept to append to). Retention stays 30 days of
  pending measurements, drops beyond it are still counted, never silent.
- **`oldest_seq` now announces the oldest measurement the probe can still
  PROVIDE** (the oldest pending one), not the oldest stored one. The probe never
  resends an acknowledged measurement; announcing one made a hub wait forever for
  it (seen in the field: hub stuck on `want=1089`).
- One-time migration at first boot: the pending measurements of the old file are
  streamed into the journal one by one (no full load in RAM), its watermark is
  kept if the NVS has none yet, then the old file is deleted.
- A numbering that goes backwards (probe NVS erased) discards the old journal
  instead of mixing two series.
- Host tests: 9 new cases (`test_native_segments`), 30 in total.

## [0.23.2] - 2026-09-26

### Fixed

- **A stuck BOOT button no longer triggers pairing nor starves measurements.**
  Seen in the field: the outdoor probe, untouched, sent five pairing requests
  and went ~17 min between two measurements (a button wake neither measures nor
  counts as a wake). GPIO0 read low for more than 3 s while outdoors (enclosure
  pressing the button, cable, or moisture). Pairing now starts on RELEASE of a
  press lasting 3 to 10 s; a press still held at 10 s is treated as a stuck
  button and ignored, without waiting for a release that may never come. The
  ext0 wake on BOOT is armed only if GPIO0 is high when going to sleep, so a
  stuck button cannot cause a wake storm; it is re-armed once GPIO0 is back
  high. Continuous mode applies the same gesture and ignores a stuck button
  until it is released.

## [0.23.1] - 2026-09-26

### Fixed

- **An acknowledgement beyond the probe's newest measurement is refused.** A hub
  that still tracked a previous series (probe restarted from seq=1) answered
  `ack<=945` to a probe at seq 6; accepting it marked measurements "delivered"
  that the hub had never archived. `markSyncedUpTo` now ignores any ack above the
  newest seq in the buffer, and `repairWatermark()` (at boot) turns an already
  inconsistent watermark back to 0 so the buffered measurements are retransmitted
  (the hub deduplicates). Pairs with MeteoHub 1.46.1, which detects the counter
  restart on its side. No protocol change. Two host tests added.

### Changed

- Hardware pairing validated on the real probe and hub (long press on BOOT,
  confirmation acknowledged, `reprise apres seq=` logged by the hub).
- TX power log no longer mentions the retired C3 board.

## [0.23.0] - 2026-09-26

### Added

- **Hub pairing by a long press on BOOT.** The probe still talks to a single
  MeteoHub in unicast, but the hub MAC now lives in NVS (`mhpair/hub`, one
  CRC-protected blob written atomically) instead of being compiled in. Holding
  BOOT ~3 s (solid blue LED) starts a pairing: the probe broadcasts a request on
  channels 1..13, the hub answers with its STA MAC, SoftAP BSSID, channel and
  name, then the probe confirms in unicast and waits for the 802.11 ACK before
  writing anything. 3 green flashes = paired, 3 red = failed.
- **A failed pairing never erases the current association**: no hub, no ACK on
  the confirmation, NVS write failure or timeout (60 s) all leave the previous
  MAC untouched, in NVS, in RAM and in the ESP-NOW peer table.
- **Several hubs in range.** A full sweep is done before deciding; if two
  different hubs answer, pairing is refused rather than guessed. Once paired,
  the channel scan matches the exact BSSID of the paired hub's "MH-NOW" SoftAP
  instead of the first "MH-NOW" seen.
- **Seamless takeover.** The confirmation carries the last sequence acknowledged
  by the previous hub; the new hub resumes from there and only asks for the
  measurements still pending (no 30-day backlog replay).
- **Wake on BOOT from deep sleep** (ext0, RTC pull-up). A button wake is not a
  measurement interval: it does not measure, does not advance the probe clock,
  and goes back to sleep for the remaining time until the scheduled wake.
- Pairing logic is pure and host-tested (`include/pairing/pairing_logic.h`,
  `test/test_native_pairing`, 8 cases). `meteo_packet.h` gains `MeteoPairFrame`
  (magic 'M','P', 44 bytes) and compiles natively.

### Changed

- `ESPNOW_RECEIVER_MAC` is now only the default used while no pairing is stored,
  so an already deployed probe keeps its hub after the update. Set it to zeros
  for a brand-new probe, which then waits to be paired (measurements kept).
- Requires MeteoHub >= 1.46.0 to answer pairing requests (older hubs simply
  ignore them; normal operation is unaffected).

## [0.22.0] - 2026-09-22

### Fixed

- **Retransmitted measurements no longer get an unusable timestamp (field test).**
  Buffered measurements stamped BEFORE the probe knew the wall-clock time carry a
  relative timestamp. Once the probe is aligned to the hub's real time, a live
  frame is absolute while those old buffered frames are still relative; the hub,
  with a single anchor, reconstructed the relative ones against an absolute anchor
  and produced an out-of-range time, so the hub dropped them ("implausible ts").
  Fix: when retransmitting, a relative stored timestamp is converted to absolute on
  the fly (`stored + (real_now - relative_now)`) if the probe now has real time, so
  the hub always receives a usable acquisition time and archives the measurement.

## [0.21.0] - 2026-09-22

### Fixed

- **Gap recovery now actually happens (field test fix).** Retransmission used to
  depend on receiving the hub's `SyncControl` inside a 300 ms window right after
  the live send. A timing race cleared the "control received" flag just after the
  reply had already arrived, so the probe almost never acted on it and never
  retransmitted - measurements missed during a hub outage stayed stuck on the
  probe (hub cumulative ACK frozen). Two fixes:
  - the reverse-channel capture is now armed BEFORE the live send, so a fast reply
    is no longer lost to the race;
  - **retransmission is now PROACTIVE**: after a successful live send the probe
    re-pushes a bounded batch of its oldest PENDING measurements regardless of
    whether a `SyncControl` was received. The hub dedups by seq, and the cumulative
    ACK (when received) trims the backlog. Delivery no longer hinges on catching the
    reply at the right millisecond.

### Notes

- No power change in steady state: with nothing pending beyond the live frame, the
  batch is empty and nothing extra is sent. Extra sends happen only during a
  catch-up, and stay capped (`SENSOR_RETX_MAX_PER_CYCLE`).

## [0.20.0] - 2026-09-22

### Added

- **Absolute time alignment from the hub, at zero power cost.** The hub's
  NTP-synced epoch now rides in the `SyncControl` reply the hub already sends
  during the probe's wake window; the probe sets its system clock
  (`settimeofday`), and the ESP32 keeps it across deep sleep. Each measurement is
  then timestamped in ABSOLUTE time at acquisition, so a buffered measurement keeps
  its correct time even across a probe power loss (the previous physical limit).
  No extra radio, scan or wake time - only 4 extra bytes in an already-sent reply
  and a microsecond `settimeofday`. The relative-clock reconstruction remains as a
  fallback until the first alignment.

### Notes

- `SyncControl` grew from 16 to 20 bytes (`hub_epoch`). Reflash probe and hub
  together (requires MeteoHub >= 1.40.0).

## [0.19.0] - 2026-09-22

### Added

- **Loss-tolerant measurement sync (ESP-NOW protocol v3).** Every measurement is
  now written to a persistent local ring buffer in flash BEFORE any send, and is
  only marked SYNCED once the hub confirms it (cumulative ACK) - never merely
  because it was sent. The buffer targets ~30 days of retention (8640 slots of
  32 B on the `spiffs` partition, ~270 KB, ~19% of it); LittleFS provides the
  flash wear leveling, the ring provides the bounded retention. On each normal
  wake the probe sends the live measurement, then within a short bounded RX window
  applies the hub's cumulative ACK and retransmits a capped batch of the
  still-missing measurements. Deep sleep and autonomy are preserved: the sync is
  bounded per cycle and the probe always returns to deep sleep, even if the hub is
  unreachable or the buffer fails to mount.
- **Monotonic sequence and relative clock persisted in NVS.** The sequence number
  now survives a power cycle/brownout (it used to reset in RTC RAM), giving each
  measurement a stable unique id for dedup and gap detection. A relative sensor
  clock (also in NVS) lets the hub reconstruct each measurement's real acquisition
  time instead of its arrival time.
- **Explicit full-buffer policy.** If communication stays down long enough to fill
  the whole buffer with unacked measurements, the oldest PENDING is overwritten to
  keep the freshest data, counted (`dropped_pending`) and logged - never a silent
  loss.
- **Native unit tests** (`pio test -e native`) covering the buffer logic: append,
  ring rotation, cumulative watermark, bounded retransmit selection, reboot
  persistence, full-buffer PENDING drop, no duplicates.

### Changed

- The sequence number is no longer held in RTC RAM; it is owned by the new
  SyncManager and persisted in NVS.

### Notes

- Requires MeteoHub >= 1.39.0. The two must be reflashed together: a v3 receiver
  rejects a different protocol version.
- Physical limit (no RTC on the probe): across a probe POWER LOSS, measurements
  buffered but not yet synced before the outage are placed relative to the return.
  Needs real-hardware validation.

## [0.18.1] - 2026-09-16

### Changed

- **Default back to deep sleep** (`USE_LIGHT_SLEEP = false`). First isolating the
  hardware: a second, supposedly identical S3 module is being tested in deep sleep
  on the same Breadvolt, to tell whether the dropout is the board itself rather
  than the firmware or the module. The light-sleep option stays available (set it
  back to true to test).

## [0.18.0] - 2026-09-16

### Added

- **Light-sleep mode (`USE_LIGHT_SLEEP`, experimental).** Alternative to deep
  sleep for battery power: light sleep keeps RAM/context (no reboot) and draws
  noticeably more current (~hundreds of µA vs ~10 µA). Diagnostic: on the Breadvolt
  module the probe drops out only after deep-sleep cycles (never on USB); the
  AP2004H boost likely can't hold the rail at the deep-sleep µA load, browning out
  the RTC so the timer wake never fires. Light sleep loads the boost more - a
  hardware-free test. When true it takes precedence over `ENABLE_DEEP_SLEEP`; the
  loop sleeps then measures on wake, incrementing `wake_count`. Set back to false
  to return to deep sleep.

## [0.17.2] - 2026-09-16

### Fixed

- **Release build fixed: packaging manifest updated to the current envs.**
  `morfproject.json` still declared the old `supermini` and `c3oled` targets, so
  `release.py` tried to build environments that no longer exist. It now declares a
  single `esp32-s3` target. (0.17.1 could not be published because of this.)

## [0.17.1] - 2026-09-16

### Changed

- **Build environment renamed `supermini` → `esp32-s3`** (single S3 target). Build
  with `pio run -e esp32-s3`. Docs updated. No firmware behaviour change.

## [0.17.0] - 2026-09-16

### Removed

- **ESP32-C3 HW-675 target dropped.** The firmware now builds for a single board,
  the **ESP32-S3 Super Mini** (env `esp32-s3`, `SENSOR_BOARD_S3`), to stay within
  one hardware family. Removed the `c3oled` environment and its U8g2 dependency,
  the `SENSOR_BOARD_C3` branch in `board_config.h`, and the C3 TX-power menu in
  `config.h`. `SENSOR_NEEDS_TX_LIMIT` stays: the S3 needs the TX cap too (full
  power yields no ACK). Docs (README en/fr, `docs/cablage.md`) updated to S3-only.

## [0.16.0] - 2026-09-16

### Added

- **Diagnostics carried in each ESP-NOW frame (protocol v2).** Every frame now
  includes `reset_reason` (esp_reset_reason of the last boot) and `wake_count` (a
  RTC counter that survives deep sleep and resets on a power cycle). Read by the
  hub on reception, they explain - without a USB cable, which is impossible for an
  outdoor probe - why the probe dropped out after a gap: a BROWNOUT/POWERON reset
  points to power (Breadvolt/cell), a wake_count jump larger than the frames
  received points to wake cycles that failed to send. Frame grows 51→54 bytes and
  the protocol version bumps to 2: the probe and MeteoHub must be reflashed
  together (a version mismatch is rejected on the hub side).

## [0.15.3] - 2026-09-15

### Documentation

- Fix a stale comment in `board_config.h` (S3 battery range said "3,0-4,2", now
  "2,6-4,2" to match `BATTERY_VOLTAGE_MIN`). No behaviour change. Verified the full
  S3 battery chain (GP4 read -> packet -> ESP-NOW -> hub parse) is correct and the
  packet struct is byte-identical between sensor and hub: a probe still reporting no
  battery is simply running pre-0.15 firmware and must be reflashed.

## [0.15.2] - 2026-09-15

### Changed

- **Battery fine-calibration factor is now per board.** `BATTERY_VREF_CALIBRATION`
  moved from `config.h` (shared) to `board_config.h` (per board): it corrects the
  ADC eFuse of a specific chip and the actual resistor tolerance, which differ
  between the C3 and the S3. The divider ratio (2.0) stays common. The C3 factor
  is set to 1.0098 (measured 2026-09-15: multimeter 4.11 V vs 4.070 V read, ~1 %);
  the S3 keeps 1.0 pending a measurement on the S3 itself.

## [0.15.1] - 2026-09-15

### Changed

- **S3 battery 0 % lowered from 3.0 V to 2.6 V.** The Breadvolt module cuts at
  2.4 V (over-discharge protection); 0 % now sits 0.2 V above that so the probe
  runs to the end instead of pinning at 0 % from 3.0 V. The plausibility guard
  (reject below MIN - 0.5 V = 2.1 V) still accepts a real near-empty cell. Note:
  below ~3.0 V the Li-ion curve collapses, so the last few percent drain fast (the
  gauge is honest, it does not extend runtime). S3 only; the C3 alkaline scale is
  unchanged.

## [0.15.0] - 2026-09-15

### Added

- **Battery reading enabled on the ESP32-S3 board.** The Breadvolt module outputs
  a constant regulated 3.3 V, so the cell is now tapped before the regulator: a
  100k/100k divider from battery+ to GP4 (`PIN_BATTERY_ADC = 4`), GP4 reading the
  midpoint (~2.0 V for 4.0 V). The firmware already had the full path; only the
  pin was flipped from -1. The shared divider ratio (2.0) and the Li-ion 3.0-4.2 V
  scale apply. The 4.28 V full-charge cell never reaches the pin directly (ADC
  limit). Wiring and calibration documented in `docs/cablage.md`.

## [0.14.2] - 2026-09-14

### Documentation

- **Wiring and notes brought in line with the current firmware.** Per-board TX
  power (C3 8.5 dBm, S3 11 dBm), unicast delivery with hardware ACK (green LED =
  frame acknowledged by the hub), S3 battery reading disabled, and the 5 min
  measurement cadence. No behaviour change.

## [0.14.1] - 2026-09-14

### Added

- **Packaging contract (`morfproject.json`)** so the probe is published in the
  parc releases like the other projects: a firmware project with two PlatformIO
  targets, `esp32-s3` (ESP32-S3) and `c3oled` (ESP32-C3), each producing a
  renamed `firmware.bin`. Picked up by `package-all.py` as a companion repo
  ("extra"), without ever entering `morf doctor` scope.

## [0.14.0] - 2026-09-14

### Changed

- **Per-board TX power.** The two PCB antennas do not behave alike, so the level is
  now set per board in config.h (guarded by `SENSOR_BOARD_*`), each with its own
  commented menu: **S3 = 11 dBm**, **C3 = 8.5 dBm** (both proven delivered on
  field logs; the S3 at full power got no ACK at all).
- **Deep sleep re-enabled** (`ENABLE_DEEP_SLEEP = true`) now that the unicast link
  is confirmed on battery, outdoors. Continuous mode drains the 14500 in hours;
  deep sleep is the autonomous mode. The unicast chain already handles the wake
  path (waits for the ACK before sleeping, keeps the channel in RTC), and the
  on-failure channel re-scan covers a hub channel migration between wakes.

## [0.13.1] - 2026-09-14

### Fixed

- **S3 delivered nothing to the hub** (unicast NACK on every attempt) while the C3
  was delivered first try on the same channel and hub MAC. USB serial logs proved
  the frame left the S3 but the hub sent no ACK, at full TX power only. Root cause:
  the ESP32-S3 Super Mini's onboard PCB antenna is poorly matched, so full power
  degrades the signal past the point the hub can acknowledge it. **TX power is now
  capped on the S3 too** (`SENSOR_NEEDS_TX_LIMIT` in board_config.h), using the
  same `SENSOR_TX_POWER_LEVEL` knob as the C3 (8.5 dBm, proven-good). Raise it via
  the config.h menu to recover range while it stays delivered.

## [0.13.0] - 2026-09-14

### Changed

- **Transmission rewritten to unicast** (clean rebuild of the whole chain). The
  sonde now sends ESP-NOW **unicast to the hub MAC** (`ESPNOW_RECEIVER_MAC`)
  instead of broadcast. This gets the hub's 802.11 hardware ACK and MAC-layer
  retransmission, far more reliable outdoors - and makes `onDataSent` a *real*
  delivery signal: `SUCCESS` now means the hub acknowledged the frame. In
  broadcast mode the callback always returned success, so the sonde blinked green
  ("sent") while the hub received nothing.
- **Self-healing channel on send failure**: if a send gets no ACK after several
  attempts, the sonde re-scans the hub's SoftAP (`MH-NOW`), switches channel and
  retries within the same cycle, instead of emitting into the void until the next
  periodic recheck. Fixes the "chaotic at 300 s interval" behaviour (a channel
  migration between sparse sends was silently dropping whole samples).

### Notes

- The green status LED now means **delivered (ACK received)**, red means **not
  delivered**. Requires that `ESPNOW_RECEIVER_MAC` is exactly the hub's **STA**
  MAC (shown on the hub's Net page / serial `sta=` line).

## [0.12.2] - 2026-09-14

### Changed

- **Deep sleep temporarily disabled** (`ENABLE_DEEP_SLEEP = false`) to isolate a
  battery-only reception issue: on USB the hub receives every cycle, on the 14500
  cell nothing reaches it. In continuous mode the radio stays initialised and the
  cold-start current spikes of each wake are avoided; if data then flows on
  battery, the fault is specific to the deep-sleep wake path (likely a brownout on
  the wake Wi-Fi burst). Field diagnostic step, to be re-enabled once resolved.

## [0.12.1] - 2026-09-14

### Fixed

- No data reaching MeteoHub in deep-sleep mode (sonde sent "ok" but the hub
  received nothing). Two deep-sleep pitfalls:
  - **TX not completing before sleep**: `esp_now_send` (broadcast) only queues the
    frame; the radio then slept before it was transmitted. Now the sonde waits for
    the send callback (`onDataSent`, up to `ACK_WAIT_MS`) before returning.
  - **Fallback channel poisoning the RTC cache**: a failed first scan cached the
    default channel (6) in RTC, so every wake emitted on the wrong channel. The
    RTC cache is now updated only on a *confirmed* scan; a failed scan is a
    one-shot fallback and the next wake re-scans.

## [0.12.0] - 2026-09-14

### Added

- **Deep sleep enabled** (`ENABLE_DEEP_SLEEP = true`): wake → measure → send →
  deep sleep, every `SENSOR_MEASUREMENT_INTERVAL_SECONDS` (5 min). Fits the small
  14500 cell - continuous mode drained it in hours.
- **Channel kept in RTC memory** across sleeps and reused on wake, so the ~2 s
  Wi-Fi scan is not paid on every wake. It is still re-scanned periodically
  (`ESPNOW_RESCAN_EVERY_N_WAKES`, ~1 h at 5 min) to catch a hub channel change;
  `applyChannel` updates the RTC cache so any switch persists across sleeps.

## [0.11.0] - 2026-09-14

### Changed

- S3 Super Mini power is now a **Breadvolt module + 14500 Li-ion** (3.7 V,
  500 mAh) delivering a **regulated 3.3 V**. Since the board only sees the
  regulated rail (not the cell), **battery sensing is disabled on the S3**
  (`PIN_BATTERY_ADC = -1`): no false static percentage or low-battery alert. The
  module handles protection (2.4 V cutoff / 4.28 V) and shows charge via its
  CHG/PWR LEDs; when the cell empties the sonde simply stops (MeteoHub shows OUT
  absent). The Li-ion range (3.0-4.2 V) is kept for the case where the raw cell
  is tapped to GP4. The C3 is unchanged (alkaline).

## [0.10.0] - 2026-09-14

### Changed

- Measurement cadence is now `SENSOR_MEASUREMENT_INTERVAL_SECONDS` in config.h,
  **default 300 s (5 min)** instead of 30 s - weather changes slowly, and 30 s
  over-samples. Single source of truth (drives the continuous loop and the future
  deep-sleep cycle), easy to change for tests (30 / 120 / 300 / 600). The indoor
  side (MeteoHub) uses the same cadence so IN and OUT history stay homogeneous.

## [0.9.2] - 2026-09-14

### Docs

- Rewrite `docs/cablage.md` for both boards (C3 HW-675 and S3 Super Mini): full
  pinout tables, shared I2C sensors, alkaline battery wiring/range, and a
  dedicated status-LED (WS2812/NeoPixel) section explaining when it lights, why,
  and what each colour means (blue = working, green = frame sent, red = send
  failure, off = idle), including the broadcast "sent ≠ received" nuance.

## [0.9.1] - 2026-09-13

### Fixed

- S3 Super Mini battery range set to 2x alkaline (2.0-3.2 V) like the C3 (was
  Li-ion): both boards run on alkaline cells for now. A 0 % at 3.26 V seen
  earlier was on USB power (no cell on the divider), not a real reading.

## [0.9.0] - 2026-09-13

### Added

- **Adaptive ESP-NOW channel.** The hub follows the Livebox channel (not fixed),
  so the sensor now discovers it by scanning the hub's "MH-NOW" SoftAP beacon at
  startup (falling back to `ESPNOW_HUB_CHANNEL` if not found). In continuous mode
  it re-scans every `ESPNOW_CHANNEL_RECHECK_SEC` (5 min) and switches if the
  channel changed; the re-scan is skipped when the battery is below
  `ESPNOW_RESCAN_SKIP_BELOW_PCT` (a Wi-Fi scan costs power, and a battery-caused
  silence is not a channel problem). Deep-sleep wake re-scans via begin(). The
  broadcast peer now uses channel 0 (follows the radio), so switching channel
  needs no peer re-registration.

## [0.8.0] - 2026-09-13

### Changed

- Drop OLED management on the ESP32-S3 Super Mini to lower power consumption:
  `SENSOR_HAS_OLED` is no longer defined for the S3, so `DisplayManager` is a
  no-op and the screen is never powered on (it stays in its low-power reset
  state). U8g2 is dropped from the S3 build. The S3 is LED-only again; the C3
  keeps its integrated OLED.

## [0.7.3] - 2026-09-13

### Fixed

- C3 battery range corrected to **2x alkaline 1.5 V** (2.0-3.2 V), not LiFePO4:
  0.7.2 mislabelled the chemistry, so a nominal 3.0 V pack still read ~14 %. Now
  ~3.0 V reads ~83 %.
- The battery plausibility guard is now derived from the board's voltage range
  (±0.5 V) instead of a hard-coded Li-ion window, so a genuinely low pack (down
  toward MIN) is still reported instead of being dropped as "no divider".

## [0.7.2] - 2026-09-13

### Fixed

- Battery percentage used a Li-ion scale (3.3-4.2 V) for every board. The C3 runs
  on LiFePO4 (~2.9-3.6 V, ~3.3 V nominal), so a healthy cell read as 0 % and made
  MeteoHub raise a false low-battery alert. The 0 %/100 % voltage range is now
  per board in board_config.h: C3 = LiFePO4 (2.9-3.6 V), S3 = Li-ion (3.3-4.2 V).
  The divider ratio stays shared (same wiring).

## [0.7.1] - 2026-09-13

### Changed

- Move the ESP-NOW TX power level (`SENSOR_TX_POWER_LEVEL`) from board_config.h
  to config.h: it is a tunable setting, not board wiring. board_config.h keeps
  only the board trait `SENSOR_NEEDS_TX_LIMIT`.

## [0.7.0] - 2026-09-13

### Changed

- C3 ESP-NOW TX cap is now configurable via `SENSOR_TX_POWER_LEVEL`
  (board_config.h). Under test at **15 dBm** (was 8.5 dBm) for better range with
  the MeteoHub S3; easy to revert if the link degrades.

### Added

- OLED status line now shows the battery **voltage** (e.g. `3.95V`) alongside
  the percentage (72x40 shows voltage compactly).

## [0.6.1] - 2026-09-13

### Added

- OLED support on the ESP32-S3 Super Mini too: an external 0.96" SSD1306
  128x64 wired on the sensor I2C bus (GP8 SDA / GP9 SCL) now shows the reading.
  `DisplayManager` picks the U8g2 driver and layout by board (72x40 on the C3
  HW-675, 128x64 on the S3), driven by `SENSOR_OLED_*` in `board_config.h`.

## [0.6.0] - 2026-09-13

### Added

- Dual board target: the sensor now builds for both the ESP32-S3 Super Mini
  (env `esp32-s3`, LED-only) and the ESP32-C3 HW-675 (env `c3oled`), selected
  by a `SENSOR_BOARD_*` define. Board pinout lives in `board_config.h`.
- C3 HW-675 integrated 0.42" OLED (SSD1306 72x40) support via U8g2, in a new
  `DisplayManager` module. Shows T/H/P, channel, TX status and battery. The
  module is a no-op on the S3 (no screen), so `main.cpp` calls it unconditionally.

### Changed

- C3 uses the board default I2C pins GP5 (SDA) / GP6 (SCL), the bus shared with
  the onboard OLED; the AHT20/BMP280 sit on that same bus.
- C3 caps ESP-NOW TX power at 8.5 dBm (`WiFi.setTxPower(WIFI_POWER_8_5dBm)`),
  guarded by `SENSOR_NEEDS_TX_LIMIT`. At full power the C3 -> S3 hub link is
  unreliable; this is a hardware constraint validated by test, do not raise it
  without re-testing on that board pair. The S3 keeps full power.

## [0.5.6] - 2026-09-12

### Changed

- Stop using the NeoPixel as a power-on glow. Status blinks then LED off.

## [0.5.5] - 2026-09-12

### Changed

- Keep a dim red power glow on the onboard LED so the node looks powered
  at a glance. Still off before deep sleep.

## [0.5.4] - 2026-09-12

### Changed

- Name I2C pins `PIN_SENSOR_SDA` (GP8) and `PIN_SENSOR_SCL` (GP9) so board
  config matches the module wiring at a glance.

## [0.5.3] - 2026-09-12

### Changed

- Single Serial dump of the full ESP-NOW payload after send (T/H/P/fields/seq).

## [0.5.2] - 2026-09-12

### Fixed

- I2C locked to SDA=GP8 / SCL=GP9 (scan on this Super Mini).
- Drop the boot pin probe that restarted the bus and confused Adafruit.
- Ignore battery ADC when GP4 is floating (0.3-1.5 V garbage).
- Log the real STA MAC bytes, not characters from the String.

## [0.5.1] - 2026-09-12

### Fixed

- Probe I2C pin pairs at boot (GP9/GP8, GP5/GP6, and swapped) so AHT/BMP
  are found if the C3 wiring was reused.
- Fill magic, node id and sequence before ESP-NOW send (hub was getting Seq 0).
- Accept BME280 chip id 0x60 on the BMP library path.

## [0.5.0] - 2026-09-12

### Changed

- Target board is now ESP32-S3 Super Mini (4 MB flash, no PSRAM, USB CDC).
- Dropped the 0.42" OLED and U8g2; status is RGB LED plus serial logs.
- I2C is opened explicitly on GP9 (SDA) / GP8 (SCL).
- Battery ADC moved to GP4. Rain pulse on GP7 (avoid GPIO 3 strapping).
- RGB LED on GPIO 48 (GPIO 46 is input-only on ESP32-S3).

## [0.4.1] - 2026-09-12

### Changed

- Reverted to classic ESP-NOW mode with AP connection.
- Sensor now connects to MH-NOW AP for reliable communication.
- Broadcast ESP-NOW mode restored with AP-based channel sync.

## [0.4.0] - 2026-09-12

### Changed

- Simplified ESP-NOW sender to use unicast direct mode instead of broadcast.
- Removed complex AP connection logic and channel scanning.
- Added direct peer registration for MeteoHub STA MAC (20:6E:F1:85:58:68).
- Improved send logic with channel stabilization delay before ESP-NOW init.

## [0.3.16] - 2026-09-12

### Fixed
- `join=0` forever after a failed boot join: retry `MH-NOW` on every send,
  scan and log RSSI/absent. Channel lock + broadcast is no longer the
  happy path while the probe is not associated.

## [0.3.15] - 2026-09-12

### Changed
- Same channel was not enough: the S3 STA never ACKs ESP-NOW from a
  disconnected C3. The probe now joins the hub AP `MH-NOW` (WPA2) and sends
  unicast to that BSSID. OLED `STA ch6` / log `join=1`.

## [0.3.14] - 2026-09-12

### Fixed
- `want=6 radio=6` but hub `rx=0`: TX ran with promiscuous ON, so frames were
  not valid ESP-NOW for the S3 STA. Channel lock is a short pulse, then
  promiscuous off before `esp_now_send`. HT20 11b/g/n.

## [0.3.13] - 2026-09-12

### Fixed
- Sweep 1-13 was not the missing piece: payload is valid and ch=6 was already
  first. Unicast never ACKs, then TX hops to 12/13. Send only on
  `ESPNOW_HUB_CHANNEL` (6) and log `radio=` vs `want=` at `esp_now_send`.

## [0.3.12] - 2026-09-12

### Fixed
- Serial capture that only keeps ESP_LOG lines (`[I]/[W]/[E]`) hid every
  `Serial.printf` ESP-NOW message, so it looked like nothing was sent after
  the I2C/ADC HAL lines. Send path now also uses `ESP_LOGI("meteo", ...)`.
  Missing AHT/BMP still transmits (empty T/H/P).

## [0.3.11] - 2026-09-12

### Added
- Serial dump of the full ESP-NOW payload (T/H/P, flags, CRC, hex) so an empty
  meteo packet (no AHT/BMP) is obvious. OLED shows `pas T/H/P` instead of a
  fake "Sensors OK".

### Fixed
- After `Bcst x13` the hub still had `rx=0`: keep promiscuous on during TX so
  the disconnected STA does not hop off channel 6 before `esp_now_send`.
  Default PHY rate (drop forced 1 Mbps). Peer channel 0 = current radio.

## [0.3.10] - 2026-09-12

### Fixed
- Hub log `ch=6 rx=0`: the probe scanned another 2.4 GHz channel and kept
  promiscuous ON, so the S3 never saw ESP-NOW. Unicast starts on
  `ESPNOW_HUB_CHANNEL` (6). Channel lock is a short promiscuous pulse, then off.

## [0.3.9] - 2026-09-12

### Fixed
- `Bcst x1` after cutting repeaters still missed the hub: unicast ACK failed
  and broadcast went only to the one scanned 2.4 GHz channel. If the S3 is on
  another 2.4 GHz channel, sweep broadcast 1-13. OLED `Bcst x13` means that
  sweep ran.

## [0.3.8] - 2026-09-12

### Fixed
- `Bcst ch11` did not mean the hub heard anything: broadcast was sent only on
  the last tried channel. Broadcast now goes out on every SSID channel seen
  (box vs repeater).

## [0.3.7] - 2026-09-12

### Fixed
- `ERR ch2` after a correct scan: unicast ACK to a stale hub STA MAC fails.
  After unicast fails, send the same frame as STA broadcast (the hub already
  listens). OLED shows `Bcst chN` vs `OK chN`. Keep promiscuous on so the C3
  does not hop off the locked channel.

## [0.3.6] - 2026-09-12

### Fixed
- `ERR ch11` with a valid scan: wait longer for the ESP-NOW ACK, retry, and
  try every 2.4 GHz channel where the SSID was seen (repeater vs box). Send
  callback no longer prints on the Wi-Fi task.

## [0.3.5] - 2026-09-12

### Changed
- Channel comes from a SSID scan only (this project's `secrets.h`). No STA
  association, no WiFiMulti, no AUTH_EXPIRE loop.

## [0.3.4] - 2026-09-12

### Fixed
- After AUTH_EXPIRE, stop the STA handshake so it does not keep hopping the
  radio. ESP-NOW uses the scanned beacon channel instead of config fallback,
  which caused `Peer channel is not equal to the home channel`.

## [0.3.3] - 2026-09-12

### Changed
- STA join uses Arduino `WiFiMulti` on this project's `include/secrets.h`, then
  `WiFi.channel()` for ESP-NOW. Boot OLED no longer prefixes the wait with
  ERREUR.

## [0.3.2] - 2026-09-12

### Changed
- Real STA association from this project's `include/secrets.h` only (`sizeof`
  the credential array). Scan, then `WiFi.begin` with channel and BSSID; stay
  associated so ESP-NOW follows the AP. Fallback to RTC / config channel only
  if WPA fails.

## [0.3.1] - 2026-09-12

### Changed
- Channel discovery uses a 2.4 GHz scan of SSIDs in `include/secrets.h` instead
  of WPA association. ESP32-C3 was failing with AUTH_EXPIRE / AUTH_FAIL; the
  beacon already carries the channel.

### Fixed
- Skip a second `Wire.begin()` after the OLED has already opened I2C.

## [0.3.0] - 2026-09-12

### Added
- At cold boot the probe associates briefly using `include/secrets.h` (same Wi-Fi
  list as the station), reads the AP channel, then drops DHCP and locks ESP-NOW
  on that channel. Deep-sleep wake reuses the RTC-cached channel.

## [0.2.2] - 2026-09-12

### Fixed
- ESP-NOW actually unicasts to the MeteoHub S3 STA MAC (`20:6E:F1:85:58:68`). The
  0.2.1 changelog claimed this, but the firmware still sent to broadcast
  `FF:FF:FF:FF:FF:FF`, so `NOW: OK` meant "frame left the radio", not "hub ACKed".
- Peer is registered on `WIFI_IF_STA`.

## [0.2.1] - 2026-09-11

### Changed
- Configured unicast ESP-NOW receiver MAC address for MeteoHub S3 (`20:6E:F1:85:58:68`).
- Automated version injection via `scripts/version.py`: the root `VERSION` file is now the single source of truth dynamically rendered on the OLED splash screen.

## [0.2.0] - 2026-09-11

### Added
- Added HW-675 ESP32-C3 board target with integrated 0.42" OLED display (SSD1306 72x40) and WS2812B RGB status LED.
- Implemented `DisplayManager` module using U8g2 library with splash screen and real-time status rendering (Node ID, sequence number, battery percentage, live sensor readings, ESP-NOW TX status).
- Implemented RGB status feedback in `PowerManager` (blue on boot/measure, green on successful transmission, red on error).
- Added low-power screen sleep/wake management for deep-sleep cycles.
- Updated board configuration and wiring documentation for HW-675 pinout.

## [0.1.0] - 2026-09-11

### Added
- Initial release of MeteoHubSensor (outdoor weather node on ESP32-C3).
- Direct ESP-NOW wireless transmission to MeteoHub ESP32-S3 station.
- Modular sensor architecture (I2C AHT20 / BMP280 with pluggable sensor slots).
- Extensibility hooks for future sensors: anemometer (pulses), wind vane (ADC), rain gauge (pulses), light.
- Battery monitoring via ADC with calibrated divider support.
- Deep-sleep and periodic measurement cycles for ultra-low power consumption.
- Structured binary packet format (`MeteoPacket`) with node ID, sequence counter, metrics, sensor validity bitmask, and CRC.
- Detailed wiring, hardware, and integration documentation in `docs/`.

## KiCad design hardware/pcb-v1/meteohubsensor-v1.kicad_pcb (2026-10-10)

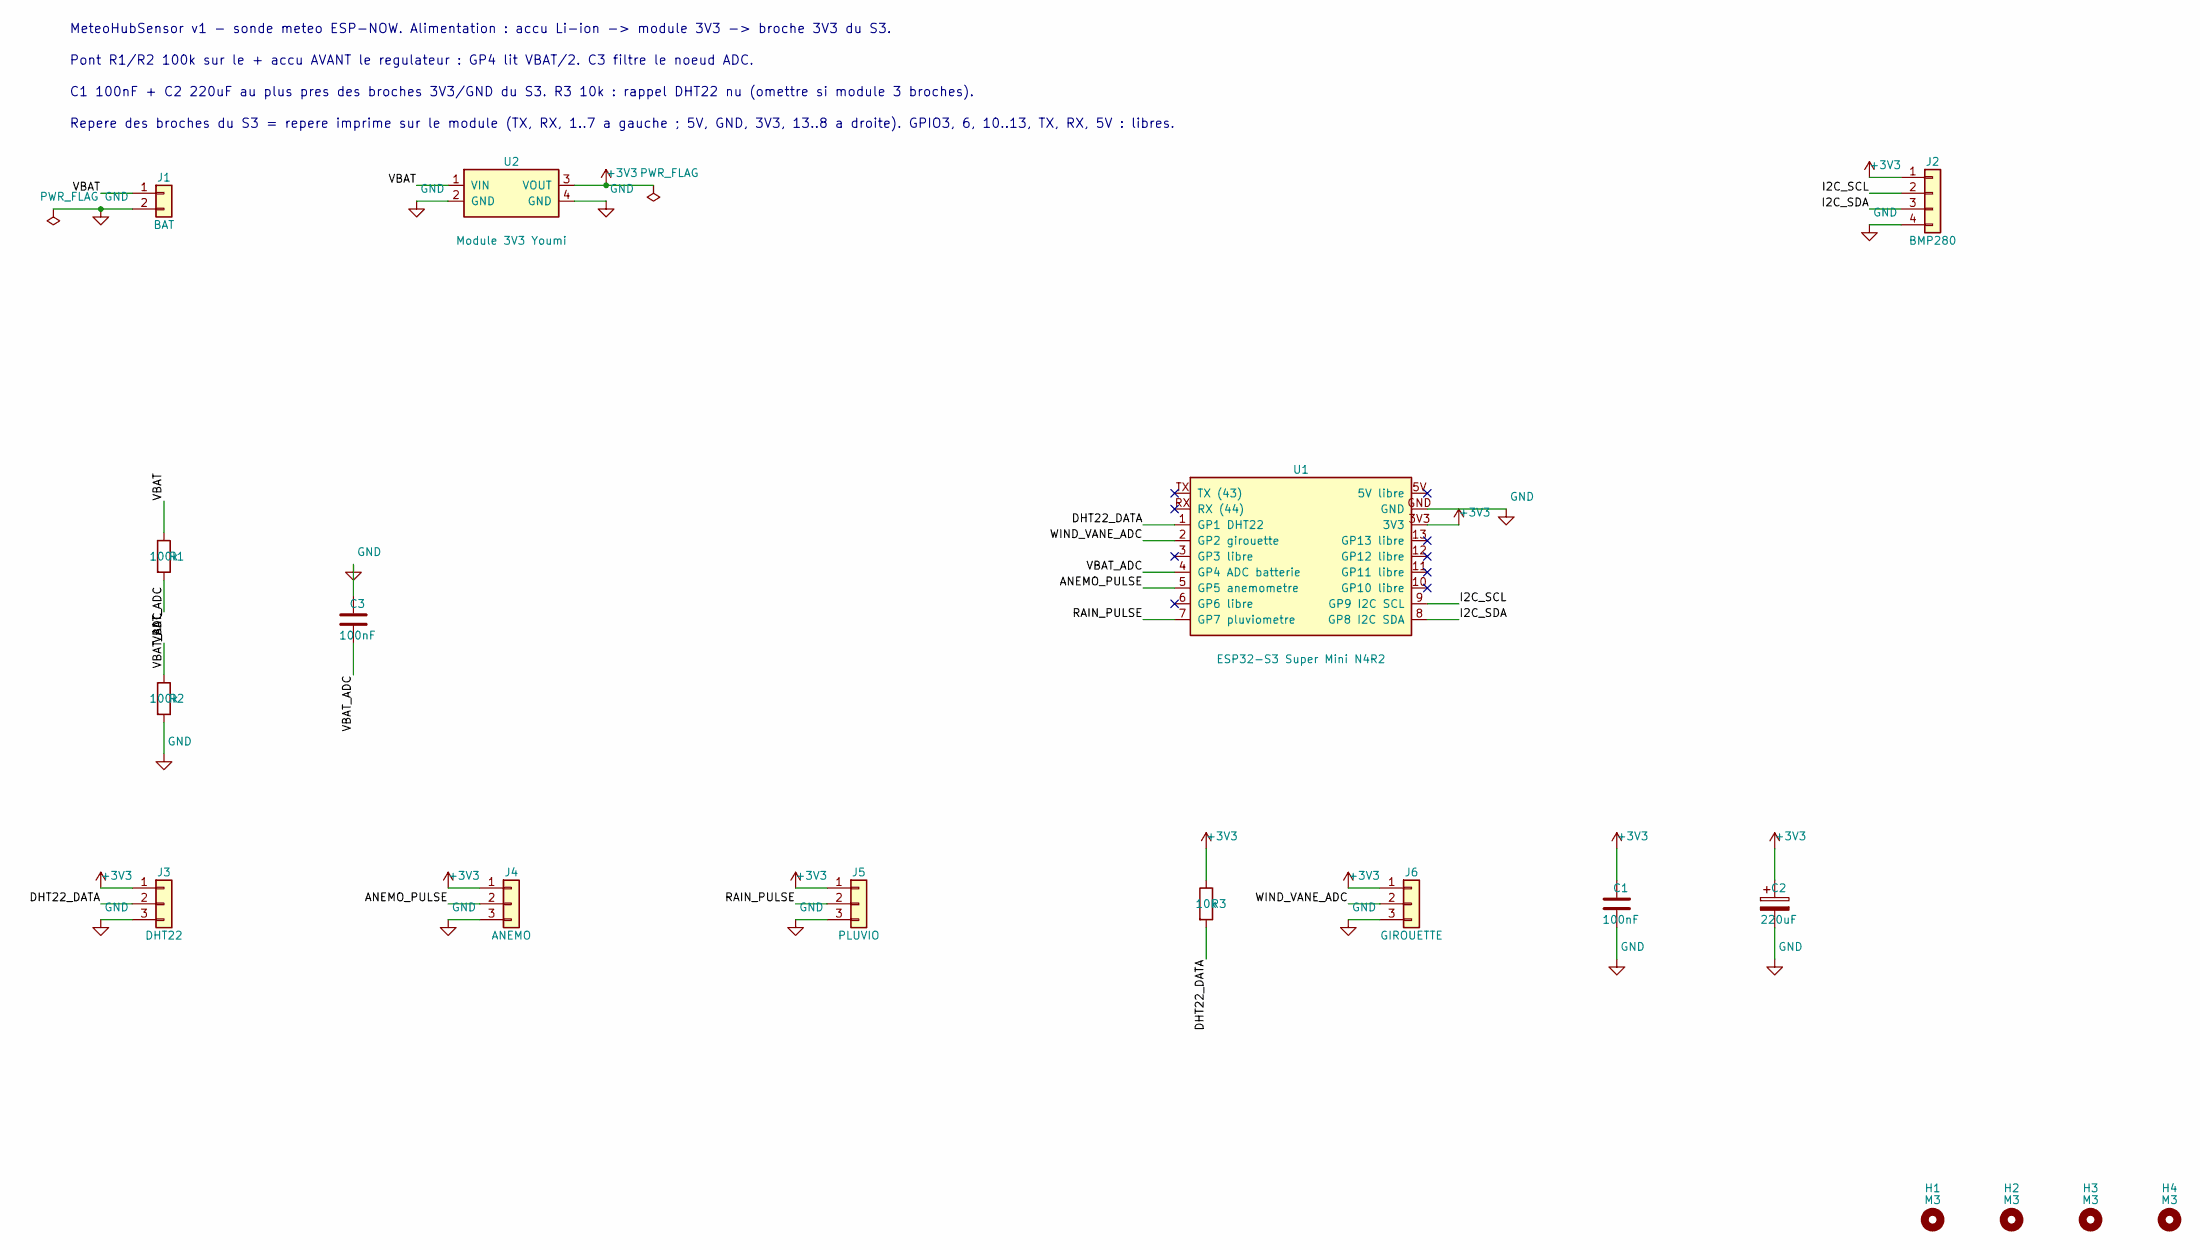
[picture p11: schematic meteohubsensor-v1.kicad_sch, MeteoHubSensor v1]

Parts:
C1, C3: 100nF; C_Disc_D3.0mm_W2.0mm_P2.50mm
C2: 220uF; CP_Radial_D6.3mm_P2.50mm
H1, H2, H3, H4: M3; MountingHole_3.2mm_M3
J1: BAT; JST_XH_B2B-XH-A_1x02_P2.50mm_Vertical
J2: BMP280; JST_XH_B4B-XH-A_1x04_P2.50mm_Vertical
J3: DHT22; JST_XH_B3B-XH-A_1x03_P2.50mm_Vertical
J4: ANEMO; JST_XH_B3B-XH-A_1x03_P2.50mm_Vertical
J5: PLUVIO; JST_XH_B3B-XH-A_1x03_P2.50mm_Vertical
J6: GIROUETTE; JST_XH_B3B-XH-A_1x03_P2.50mm_Vertical
R1, R2: 100k; R_Axial_DIN0207_L6.3mm_D2.5mm_P2.54mm_Vertical
R3: 10k; R_Axial_DIN0207_L6.3mm_D2.5mm_P2.54mm_Vertical
U1: ESP32-S3 Super Mini N4R2; ESP32-S3_SuperMini_Socket
U2: Module 3V3 Youmi; Regulator_Module_3V3

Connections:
+3V3: C1.1, C2.1, J2.1, J3.1, J4.1, J5.1, J6.1, R3.1, U1.3V3, U2.3 (VOUT)
/ANEMO_PULSE: J4.2, U1.5 (GP5 anemometre)
/DHT22_DATA: J3.2, R3.2, U1.1 (GP1 DHT22)
/I2C_SCL: J2.2, U1.9 (GP9 I2C SCL)
/I2C_SDA: J2.3, U1.8 (GP8 I2C SDA)
/RAIN_PULSE: J5.2, U1.7 (GP7 pluviometre)
/VBAT: J1.1, R1.1, U2.1 (VIN)
/VBAT_ADC: C3.2, R1.2, R2.1, U1.4 (GP4 ADC batterie)
/WIND_VANE_ADC: J6.2, U1.2 (GP2 girouette)
GND: C1.2, C2.2, C3.1, J1.2, J2.4, J3.3, J4.3, J5.3, J6.3, R2.2, U1.GND, U2.2 (GND), U2.4 (GND)

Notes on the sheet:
MeteoHubSensor v1 - sonde meteo ESP-NOW. Alimentation : accu Li-ion -> module 3V3 -> broche 3V3 du S3.
Pont R1/R2 100k sur le + accu AVANT le regulateur : GP4 lit VBAT/2. C3 filtre le noeud ADC.
C1 100nF + C2 220uF au plus pres des broches 3V3/GND du S3. R3 10k : rappel DHT22 nu (omettre si module 3 broches).
Repere des broches du S3 = repere imprime sur le module (TX, RX, 1..7 a gauche ; 5V, GND, 3V3, 13..8 a droite). GPIO3, 6, 10..13, TX, RX, 5V : libres.

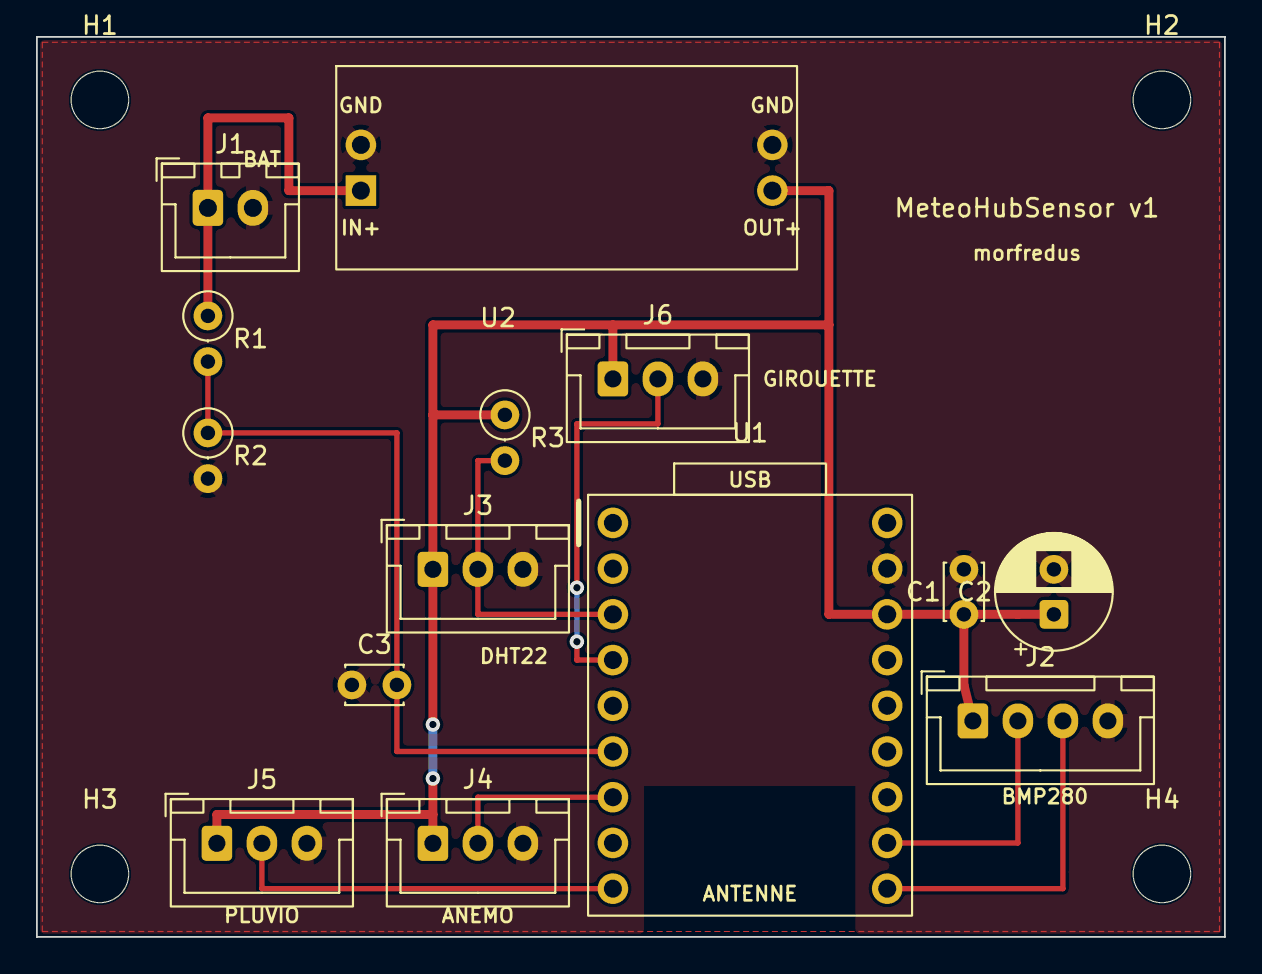
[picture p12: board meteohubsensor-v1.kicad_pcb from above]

Board: 2 copper layers, 66.0 x 50.0 mm, 18 parts (0 on the bottom side), 10 nets.

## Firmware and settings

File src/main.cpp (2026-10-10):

#include <Arduino.h>
#include <esp_system.h>   // esp_reset_reason() pour le diagnostic (paquet v2)
#include <esp_sleep.h>    // esp_light_sleep_start() (mode light sleep experimental)
#include <driver/rtc_io.h> // liberation de GPIO0 apres un reveil ext0 (bouton BOOT)
#include "board_config.h"
#include "config.h"
#include "meteo_packet.h"
#include "modules/sensor_manager.h"
#include "modules/espnow_sender.h"
#include "modules/power_manager.h"
#include "modules/sync_manager.h"
#include "modules/ota_updater.h"
#include "ota/ota_logic.h"

// Instance globale des modules
static SensorManager sensorManager;
static EspNowSender espNowSender;
static PowerManager powerManager;
static mhs::SyncManager syncManager;   // buffer local + identite + horloge (v3)

// Compteur de cycles d'exécution
static uint32_t lastMeasurementTime = 0;
static uint32_t lastChannelCheck = 0;

// Dernier état batterie connu (pour sauter la revérification de canal quand la
// pile est presque vide : ne pas gaspiller le peu qui reste en scans Wi-Fi).
static bool g_lastBatteryValid = false;
static uint8_t g_lastBatteryPct = 100;
static float g_lastBatteryV = 0.0f;

// --- Mise a jour OTA proposee par le hub ------------------------------------
// L'offre est captee pendant la synchro (SYNC_FLAG_OTA_OFFER), traitee en fin de cycle.
// Version tentee + nombre d'essais en RTC : survivent au deep sleep (voir mhota::decide).
// Balise lue par le HUB dans le binaire televerse : c'est ainsi qu'il connait la version, sans
// saisie. Elle est LUE au demarrage (banniere) : sans reference,
// l'editeur de liens (gc-sections) l'eliminerait malgre `used`. NE PAS ecrire « MHSFW= » ailleurs.
static const char kFwTag[] __attribute__((used)) = "MHSFW=" PROJECT_VERSION;
// Pointeur volatile : le compilateur ne peut pas replier kFwTag + 6 en constante et jeter la balise.
static const char* volatile g_fwTag = kFwTag;

static OtaOffer g_otaOffer;
static bool g_otaOfferPending = false;
RTC_DATA_ATTR static uint32_t g_otaLastTarget = 0;
RTC_DATA_ATTR static uint8_t g_otaTries = 0;

// Le SyncControl annonce qu'une offre suit : on l'attend brievement (jamais sinon, pour ne
// rien ajouter a un reveil ordinaire).
static void noteOtaFlag(const SyncControl& ctrl) {
    if (!(ctrl.want_count & SYNC_FLAG_OTA_OFFER) || g_otaOfferPending) return;
    g_otaOfferPending = espNowSender.waitOtaOffer(g_otaOffer, OTA_OFFER_WAIT_MS);
}

static void runOtaIfOffered() {
    if (!g_otaOfferPending) return;
    g_otaOfferPending = false;
    const mhota::Verdict v = mhota::decide(g_otaOffer, encodeFwVersion(PROJECT_VERSION),
                                           g_lastBatteryValid, g_lastBatteryV,
                                           g_otaLastTarget, g_otaTries);
    if (v != mhota::Verdict::ACCEPT) {
        Serial.printf("[OTA] Offre ignoree (verdict=%d)\n", (int)v);
        return;
    }
    if (g_otaOffer.fw_version != g_otaLastTarget) {
        g_otaLastTarget = g_otaOffer.fw_version;
        g_otaTries = 0;
    }
    g_otaTries++;
    Serial.printf("[OTA] Mise a jour vers 0x%06X (%u o), essai %u/%u\n",
                  (unsigned)g_otaOffer.fw_version, (unsigned)g_otaOffer.size,
                  (unsigned)g_otaTries, (unsigned)mhota::MAX_TRIES_PER_TARGET);
    powerManager.setLedColor(150, 0, 150);
    if (otaFromHub(g_otaOffer, espNowSender.channel(), espNowSender.hubApMac())) {
        Serial.println("[OTA] Image ecrite et verifiee : redemarrage");
        delay(200);
        ESP.restart();
    }
    Serial.println("[OTA] Echec : firmware actuel conserve, nouvel essai au prochain reveil");
    powerManager.blinkStatus(150, 0, 0, 60);
    powerManager.turnOffLed();
}

// --- Appairage par appui long sur BOOT --------------------------------------
// true tant que BOOT est enfonce (bouton actif a l'etat bas).
static bool bootPressed() { return digitalRead(PIN_BOOT_BUTTON) == LOW; }

// Geste sur BOOT, lu depuis `pressStartMs` :
//   SHORT : relache avant PAIRING_LONG_PRESS_MS -> ignore ;
//   PAIR  : relache entre PAIRING_LONG_PRESS_MS et PAIRING_STUCK_MS -> appairage.
//           La LED passe au bleu des le seuil atteint : « tu peux relacher » ;
//   STUCK : toujours enfonce a PAIRING_STUCK_MS -> bouton coince, rien. On
//           n'attend pas le relachement (il peut ne jamais venir).
// L'appairage exige donc un RELACHEMENT : un faux contact permanent (boitier qui
// appuie sur le bouton, humidite) ne peut plus le declencher.
enum class BootGesture : uint8_t { SHORT, PAIR, STUCK };

static BootGesture readBootGesture(uint32_t pressStartMs) {
    bool armed = false;
    while (bootPressed()) {
        const uint32_t held = millis() - pressStartMs;
        if (held >= PAIRING_STUCK_MS) {
            powerManager.turnOffLed();
            return BootGesture::STUCK;
        }
        if (!armed && held >= PAIRING_LONG_PRESS_MS) {
            powerManager.setLedColor(0, 0, 150);
            armed = true;
        }
        delay(10);
    }
    return (millis() - pressStartMs >= PAIRING_LONG_PRESS_MS) ? BootGesture::PAIR
                                                               : BootGesture::SHORT;
}

// Procedure complete : LED bleue fixe pendant la recherche, puis 3 eclairs verts
// (appaire) ou rouges (echec, association INCHANGEE). Le nouveau hub reprend
// apres le dernier seq accuse par l'ancien : il ne reclamera que les mesures
// encore en attente.
static void runPairing() {
    Serial.println("[PAIR] Appui long sur BOOT : appairage d'un nouveau hub");
    powerManager.setLedColor(0, 0, 150);
    const PairingReport r = espNowSender.pair(syncManager.ackWatermark(), PAIRING_TIMEOUT_MS);
    const bool ok = (r.result == PairingReport::PAIRED);
    for (int i = 0; i < 3; i++) {
        powerManager.blinkStatus(ok ? 0 : 150, ok ? 150 : 0, 0, 250);
        delay(250);
    }
    powerManager.turnOffLed();
}

// Diagnostic (paquet v2) : compteur de reveils qui SURVIT au deep sleep (RTC) et
// repart de 0 a un power-cycle, plus la raison du dernier reset captee au boot.
// Emportes dans chaque trame, ils disent au hub POURQUOI la sonde a decroche.
RTC_DATA_ATTR static uint32_t g_wakeCount = 0;
static uint8_t g_resetReason = 0;

// Construit une trame de RETRANSMISSION a partir d'une mesure bufferisee : elle
// rejoue le seq et le sensor_ts D'ORIGINE (le hub reconstruira la bonne heure de
// mesure), avec les diagnostics et l'oldest_seq COURANTS.
static MeteoPacket buildRetransmitPacket(const mhs::StoredRecord& rec) {
    MeteoPacket p;
    memset(&p, 0, sizeof(p));
    p.temperature = rec.t;
    p.humidity    = rec.h;
    p.pressure    = rec.p;
    p.battery_voltage = rec.battery_v;
    p.battery_percent = rec.battery_pct;
    p.valid_fields = rec.valid_fields;
    p.sequence   = rec.seq;
    // Convertit un eventuel horodatage RELATIF (mesure stockee avant que la sonde
    // connaisse l'heure) en ABSOLU si la sonde est desormais a l'heure : le hub
    // recoit alors une heure de mesure exploitable, sans melange relatif/absolu.
    p.sensor_ts  = syncManager.absoluteTs(rec.sensor_ts);
    p.oldest_seq = syncManager.oldestSeq();
    p.reset_reason = g_resetReason;
    p.wake_count = (uint16_t)g_wakeCount;
    p.uptime_sec = millis() / 1000;
    return p;
}

// Phase de synchronisation differee, ouverte APRES un envoi live REUSSI (le hub
// est donc joignable). Deux temps :
//   1. On ECOUTE brievement un SyncControl (accuse cumulatif + heure du hub) et
//      on l'applique s'il arrive. C'est un BONUS : ca elague le backlog et recale
//      l'horloge.
//   2. On RETRANSMET D'OFFICE un lot borne de nos plus vieilles mesures PENDING,
//      que l'on ait recu ou non le SyncControl. C'est ce qui rattrape reellement
//      les trous : la livraison ne depend plus d'une reponse captee au bon
//      millieme de seconde (voie retour fragile). Le hub deduplique par seq, donc
//      repousser une mesure deja recue est sans effet.
// Bornee dans le temps ET en nombre : jamais de session illimitee. En regime
// normal (rien en attente au-dela du live), le lot est vide -> aucun envoi en
// plus, aucune conso supplementaire.
static void runDeferredSync(uint32_t liveSeq) {
    if (!syncManager.ok()) return;

    // 1) Ecoute (best-effort) de l'accuse cumulatif + heure du hub.
    SyncControl ctrl;
    if (espNowSender.receiveSyncControl(ctrl, SENSOR_SYNC_RX_WINDOW_MS)) {
        noteOtaFlag(ctrl);
        syncManager.applyHubEpoch(ctrl.hub_epoch);
        if (syncManager.applyAck(ctrl.ack_seq)) {
            Serial.printf("[SYNC] ACK cumulatif seq<=%u (reste %u en attente)\n",
                          ctrl.ack_seq, syncManager.unsyncedCount());
        }
    }

    // 2) Retransmission PROACTIVE, independante de l'etape 1 : on repousse les plus
    //    vieilles mesures encore PENDING (au-dela du filigrane), plafonnee.
    const uint32_t fromSeq = syncManager.ackWatermark() + 1;
    mhs::StoredRecord batch[SENSOR_RETX_MAX_PER_CYCLE];
    const uint32_t n = syncManager.selectRetransmit(fromSeq, SENSOR_RETX_MAX_PER_CYCLE, batch);

    uint32_t sent = 0;
    for (uint32_t i = 0; i < n; i++) {
        // On ne rejoue pas la mesure qu'on vient d'emettre en live ce cycle.
        if (batch[i].seq == liveSeq) continue;
        MeteoPacket p = buildRetransmitPacket(batch[i]);
        const bool ok = espNowSender.send(p, FRAME_RETRANSMIT);
        if (ok) sent++;
        Serial.printf("[SYNC] %s seq=%u\n", ok ? "Retransmis" : "Echec retx", batch[i].seq);
    }
    if (sent == 0) return;
    Serial.printf("[SYNC] %u mesure(s) retransmise(s) a partir de seq=%u\n", sent, fromSeq);

    // 3) Derniere ecoute courte : recolter l'accuse cumulatif mis a jour par le hub
    //    apres ce lot et marquer synced ce qui vient d'etre confirme.
    if (espNowSender.receiveSyncControl(ctrl, SENSOR_SYNC_RX_WINDOW_MS)) {
        noteOtaFlag(ctrl);
        syncManager.applyHubEpoch(ctrl.hub_epoch);
        if (syncManager.applyAck(ctrl.ack_seq)) {
            Serial.printf("[SYNC] ACK cumulatif seq<=%u apres retransmission (reste %u)\n",
                          ctrl.ack_seq, syncManager.unsyncedCount());
        }
    }
}

// `preread` : mesure deja acquise AVANT le demarrage de la radio (reveil de deep
// sleep, voir setup). nullptr : lire ici (mode continu / light sleep, radio deja
// active en permanence).
void performCycle(const MeteoPacket* preread = nullptr) {
    Serial.println("\n----------------------------------------");
    Serial.println("[MAIN] Debut du cycle de mesure");

    // Horloge relative : chaque reveil (hors tout premier boot) represente un
    // intervalle ecoule. On l'avance AVANT d'horodater la nouvelle mesure.
    if (syncManager.lastSeq() > 0) {
        syncManager.advanceClock(SENSOR_MEASUREMENT_INTERVAL_SECONDS);
    }

    MeteoPacket packet;
    if (preread) packet = *preread;             // capteurs lus radio eteinte
    else memset(&packet, 0, sizeof(MeteoPacket));
    packet.uptime_sec = millis() / 1000;
    packet.reset_reason = g_resetReason;         // diagnostic v2 (voir setup)
    packet.wake_count = (uint16_t)g_wakeCount;

    // Temoin bleu pendant l'acquisition (plus d'OLED : la LED est le statut)
    powerManager.setLedColor(0, 40, 120);

    if (!preread) sensorManager.readAll(packet);
    // Batterie lue ICI, radio active : les seuils d'alerte du hub (3,40 / 3,20 V)
    // ont ete regles sur une tension sous charge, on ne change pas sa reference.
    powerManager.readBattery(packet);
    g_lastBatteryValid = (packet.valid_fields & FIELD_BATTERY) != 0;
    g_lastBatteryPct = packet.battery_percent;
    g_lastBatteryV = packet.battery_voltage;

    // STOCKAGE AVANT ENVOI : la mesure entre dans le buffer local (avec seq +
    // sensor_ts) avant toute tentative radio. Une mesure acquise n'est donc jamais
    // perdue parce que l'envoi echoue.
    const uint32_t seq = syncManager.recordAcquisition(packet);

    // Cas-limite journalise : buffer plein d'unacked, une PENDING a ete ecrasee.
    if (syncManager.lastDroppedSeq() != 0) {
        Serial.printf("[SYNC] [WARN] Buffer plein : plus vieille PENDING ecrasee seq=%u "
                      "(total dropped=%u)\n",
                      syncManager.lastDroppedSeq(), syncManager.droppedPending());
    }

    Serial.printf("[SYNC] New measurement seq=%u sensor_ts=%u fields=0x%04X "
                  "T=%.2f H=%.2f P=%.2f\n",
                  seq, packet.sensor_ts, packet.valid_fields,
                  packet.temperature, packet.humidity, packet.pressure);

    // Arme la capture de la voie retour AVANT l'envoi : un SyncControl qui
    // arriverait dans l'instant suivant l'ACK ne doit pas etre perdu par une course
    // de timing (sinon la fenetre d'ecoute demarrait trop tard).
    espNowSender.resetSyncControl();

    // Envoi LIVE de la mesure courante.
    const bool success = espNowSender.send(packet, FRAME_LIVE);

    Serial.printf(
        "[MAIN] Paquet %u o  seq=%u  fields=0x%04X  T=%.2f  H=%.2f  P=%.2f  bat=%.2fV  ch=%u  ok=%d\n",
        (unsigned)sizeof(packet), packet.sequence, packet.valid_fields,
        packet.temperature, packet.humidity, packet.pressure,
        packet.battery_voltage, (unsigned)espNowSender.channel(), success ? 1 : 0);

    if (success) {
        Serial.printf("[SYNC] Sent seq=%u (ACK MAC ch=%u)\n", seq, (unsigned)espNowSender.channel());
        powerManager.blinkStatus(0, 150, 0, 60);
        // Le hub a recu la trame : phase de synchro differee (accuse cumulatif +
        // retransmission proactive bornee des trous).
        runDeferredSync(seq);
    } else {
        Serial.printf("[MAIN] [WARN] Echec d'envoi (seq=%u ch=%u) : mesure conservee (PENDING)\n",
                      seq, (unsigned)espNowSender.channel());
        powerManager.blinkStatus(150, 0, 0, 60);
        // Hub injoignable : rien a synchroniser maintenant, tout reste PENDING.
    }

    // Offre OTA captee pendant la synchro : traitee EN DERNIER, une fois la mesure
    // stockee, envoyee et accusee. Un echec d'OTA ne coute donc aucune donnee.
    runOtaIfOffered();

    Serial.println("----------------------------------------\n");
}

void setup() {
    // Diagnostic v2, capte AU PLUS TOT : raison du reset de ce boot + incrementation
    // du compteur de reveils (RTC). Un power-cycle a remis g_wakeCount a 0.
    g_resetReason = (uint8_t)esp_reset_reason();
    // Reveil par le bouton BOOT (ext0) : ce n'est PAS un intervalle de mesure
    // ecoule. On ne compte pas ce reveil et on ne mesure pas (l'horloge relative
    // de la sonde avance d'un intervalle a chaque reveil compte).
    const bool buttonWake = (esp_sleep_get_wakeup_cause() == ESP_SLEEP_WAKEUP_EXT0);
    const uint32_t pressStartMs = millis();
    if (!buttonWake) g_wakeCount++;

    // GPIO0 reste en mode RTC apres un reveil ext0 : le rendre au GPIO numerique
    // avant de le lire.
    rtc_gpio_deinit((gpio_num_t)PIN_BOOT_BUTTON);
    pinMode(PIN_BOOT_BUTTON, INPUT_PULLUP);

    // LED disponible au plus tot : elle sert de retour pendant l'appui.
    powerManager.begin();

    // L'appui long se mesure TOUT DE SUITE, avant l'attente USB (2 s) et le scan
    // de canal : sinon ces delais mangeraient le temps d'appui et un vrai appui
    // long passerait pour un court. LED bleue des que le seuil est atteint : on
    // peut relacher.
    BootGesture gesture = BootGesture::SHORT;
    if (buttonWake) gesture = readBootGesture(pressStartMs);
    const bool wantPairing = (gesture == BootGesture::PAIR);

    Serial.begin(115200);
    // USB CDC du Super Mini : laisser le host enumerer, sans bloquer sans cable.
    uint32_t serialWait = millis();
    while (!Serial && (millis() - serialWait) < 2000) {
        delay(10);
    }

    Serial.println();
    Serial.println("========================================");
    Serial.println("   MeteoHubSensor - Sonde Exterieure    ");
    Serial.printf("   %s\n", BOARD_NAME);
#ifdef PROJECT_VERSION
    Serial.printf("   version %s\n", g_fwTag + 6);   // lit la balise : garantit sa presence dans le binaire
#endif
    Serial.println("========================================");

    if (!wantPairing) powerManager.setLedColor(0, 50, 150);

    sensorManager.begin();

    // MESURE AVANT LA RADIO. Un reveil sur ESPNOW_RESCAN_EVERY_N_WAKES rescanne le
    // canal du hub (~2 s de radio a plein regime) dans espNowSender.begin() : lue
    // apres, la mesure de ce reveil-la subissait la chauffe et l'appel de courant
    // de la radio (pic de pression toutes les ~60 min observe le 29/09). Lire ici
    // donne a CHAQUE reveil les memes conditions : capteurs au repos, radio
    // eteinte. Lecture faite meme sur un reveil par BOOT (sans usage si aucune
    // mesure ne suit) : quelques millisecondes d'I2C, pour une seule regle simple.
    MeteoPacket preread;
    memset(&preread, 0, sizeof(MeteoPacket));
    sensorManager.readAll(preread);

    // Buffer de securite local (LittleFS + NVS). Degrade mais non bloquant s'il
    // echoue : la sonde emettra quand meme en direct, simplement sans filet.
    if (!syncManager.begin()) {
        Serial.println("[SYNC] [WARN] Buffer local indisponible : emission sans filet");
    } else {
        Serial.printf("[SYNC] Buffer pret (seq=%u, en attente=%u, dropped=%u)\n",
                      syncManager.lastSeq(), syncManager.unsyncedCount(),
                      syncManager.droppedPending());
    }

    if (!espNowSender.begin()) {
        Serial.println("[MAIN] [FATAL] Impossible d'initialiser ESP-NOW");
        powerManager.setLedColor(150, 0, 0);
    } else {
        Serial.printf("[MAIN] ESP-NOW pret, canal %u\n", (unsigned)espNowSender.channel());
        if (!wantPairing) powerManager.turnOffLed();
    }

    if (buttonWake) {
        // Reveil par BOOT : appui long -> appairage ; appui court -> rien. Dans
        // les deux cas, on se rendort pour le temps RESTANT jusqu'au reveil
        // programme, sans mesure : la cadence et l'horloge ne bougent pas.
        if (wantPairing) {
            runPairing();
        } else if (gesture == BootGesture::STUCK) {
            Serial.println("[PAIR] [WARN] BOOT enfonce en permanence (bouton coince ?) : "
                           "appairage ignore, reveil par bouton desarme");
        } else {
            Serial.println("[PAIR] Appui court sur BOOT : ignore");
        }
        const uint32_t left = powerManager.secondsUntilScheduledWake();
        if (left >= 2 && ENABLE_DEEP_SLEEP && !USE_LIGHT_SLEEP) {
            syncManager.end();
            powerManager.enterDeepSleep(left);
        }
        // Reveil programme imminent (ou mode continu) : cycle normal ci-dessous.
    }

    performCycle(&preread);
    lastMeasurementTime = millis();

    // Deep sleep = ne revient jamais (reboot au reveil). On FERME proprement le
    // buffer (flush LittleFS + NVS) avant de dormir : le retour au deep sleep est
    // garanti meme si la synchro a echoue.
    if (ENABLE_DEEP_SLEEP && !USE_LIGHT_SLEEP) {
        syncManager.end();
        delay(200);
        powerManager.enterDeepSleep(SENSOR_MEASUREMENT_INTERVAL_SECONDS);
    }
}

void loop() {
    if (USE_LIGHT_SLEEP) {
        // Light sleep : on eteint la LED, on arme le timer et on dort. La RAM et le
        // contexte sont conserves (pas de reboot) ; au reveil, l'execution reprend
        // ICI. On incremente wake_count et on refait un cycle complet (mesure +
        // envoi + synchro differee bornee).
        powerManager.turnOffLed();
        esp_sleep_enable_timer_wakeup(
            (uint64_t)SENSOR_MEASUREMENT_INTERVAL_SECONDS * 1000000ULL);
        esp_light_sleep_start();   // bloque jusqu'au timer
        g_wakeCount++;
        performCycle();
        return;
    }

    if (!ENABLE_DEEP_SLEEP) {
        // Mode continu : le bouton est surveille ici (pas de reveil ext0). Un
        // bouton coince n'est relu qu'apres un relachement, pour ne pas bloquer
        // la boucle 10 s a chaque tour.
        static bool ignoreUntilRelease = false;
        if (!bootPressed()) {
            ignoreUntilRelease = false;
        } else if (!ignoreUntilRelease) {
            const BootGesture g = readBootGesture(millis());
            if (g == BootGesture::PAIR) {
                runPairing();
            } else if (g == BootGesture::STUCK) {
                Serial.println("[PAIR] [WARN] BOOT enfonce en permanence : ignore");
                ignoreUntilRelease = true;
            }
        }

        uint32_t now = millis();
        if (now - lastMeasurementTime >= (SENSOR_MEASUREMENT_INTERVAL_SECONDS * 1000UL)) {
            lastMeasurementTime = now;
            performCycle();
        }

        // Revérification périodique du canal : le hub peut migrer de canal. On
        // rescanne « MH-NOW » et on bascule si besoin. On saute si la pile est
        // presque vide (un scan coûte, et un silence dû à la pile n'est pas un
        // problème de canal). En mode deep sleep, chaque réveil rescanne via
        // begin(), donc cette boucle ne concerne que le mode continu.
        if (now - lastChannelCheck >= (ESPNOW_CHANNEL_RECHECK_SEC * 1000UL)) {
            lastChannelCheck = now;
            const bool batteryCritical =
                g_lastBatteryValid && g_lastBatteryPct < ESPNOW_RESCAN_SKIP_BELOW_PCT;
            if (batteryCritical) {
                Serial.println("[MAIN] Revérif canal sautée (batterie critique)");
            } else {
                espNowSender.refreshChannel();
            }
        }
        delay(10);
    }
}

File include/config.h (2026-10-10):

#pragma once
#include <Arduino.h>

// ============================================================================
// Configuration générale du nœud météo extérieur (ESP32-S3 Super Mini)
// ============================================================================

// --- Identifiant de la sonde ---
constexpr uint8_t SENSOR_NODE_ID = 1; // ID unique du nœud (pour distinguer plusieurs sondes si besoin)

// --- Mode d'alimentation et Fréquence de mesure ---
// Si TRUE : mesure, émission ESP-NOW immédiate puis passage en deep sleep
// Si FALSE : boucle active millis() permanente (idéal pour debug ou alimentation secteur)
// TRUE = mode autonome sur batterie : le mode continu vide l'accu en quelques
// heures. La chaîne unicast gère le réveil (attente de l'ACK avant sommeil, canal
// mémorisé en RAM RTC). Passer à FALSE seulement pour un debug sur USB.
constexpr bool ENABLE_DEEP_SLEEP = true;

// EXPERIMENTAL (test alim) : dormir en LIGHT SLEEP au lieu de DEEP SLEEP.
//   - Deep sleep : ~10 µA, mais REBOOT au reveil (setup rejoue, RTC conservee).
//   - Light sleep : conserve la RAM/le contexte (pas de reboot), la radio se coupe
//     puis reprend, et tire NETTEMENT plus de courant (~centaines de µA).
// But du test : le module Breadvolt (boost AP2004H) semble decrocher a la charge
// tres faible du deep sleep -> le rail 3,3 V flechit, le domaine RTC brownout, la
// sonde ne se reveille plus (aucune perte en USB, seulement sur Breadvolt). Le
// light sleep charge davantage le boost : s'il tient, on a la reponse sans
// materiel. Prend le pas sur ENABLE_DEEP_SLEEP quand true. Repasser a false pour
// revenir au deep sleep une fois le test conclu.
// Remis a false : on teste d'abord un AUTRE module S3 (cense identique) en DEEP
// SLEEP, pour isoler si le decrochage vient de la carte elle-meme. L'option reste
// disponible : repasser a true pour tester le light sleep si besoin.
constexpr bool USE_LIGHT_SLEEP = false;

// Cadence de MESURE et d'émission, en secondes. NE PAS coder en dur ailleurs :
// c'est la seule source de vérité. IN (côté MeteoHub) doit utiliser la même
// cadence, pour que les deux séries de l'historique soient homogènes.
// La météo évolue lentement : 5 min est la valeur nominale. Facile à changer
// pour les tests : 30 / 120 / 300 / 600 (30 s / 2 / 5 / 10 min).
// En deep sleep (futur capteur autonome), c'est aussi la base du cycle
// énergétique : réveil -> mesure -> émission -> deep sleep -> réveil suivant.
#define SENSOR_MEASUREMENT_INTERVAL_SECONDS 300

// --- Buffer de securite local (synchronisation fiable v3) ------------------
// Historique local en Flash (LittleFS, partition « spiffs » de 1,44 Mo). Ring
// buffer borne : chaque mesure y est ecrite AVANT l'envoi et n'est declaree
// synchronisee qu'apres l'accuse cumulatif du hub. Objectif de retention 30 j.
//   30 j @ 5 min = 8640 mesures ; 8640 * 32 o + en-tete = ~270 Ko (~19 % de la
//   partition) -> les 30 jours tiennent avec une large marge.
//
// Depuis 0.24.0 : journal SEGMENTE en ajout seul (un fichier par jour de mesures
// dans SENSOR_SEGMENT_DIR), filigrane d'accuse en NVS. L'ancien fichier unique
// (SENSOR_BUFFER_PATH) etait recopie en entier par LittleFS a chaque mesure
// (4,5 s mesurees) ; il n'est plus lu qu'une fois, pour reprendre ses mesures
// en attente, puis efface.
constexpr uint32_t SENSOR_SEGMENT_RECORDS = 288;   // 1 jour @ 5 min = 9 Ko par fichier
constexpr uint32_t SENSOR_MAX_SEGMENTS    = 30;    // retention : 30 jours en attente
constexpr char     SENSOR_SEGMENT_DIR[]   = "/mhs";
// Ancien format (lecture unique a la migration).
constexpr uint32_t SENSOR_BUFFER_CAPACITY = 8640;
constexpr char     SENSOR_BUFFER_PATH[]   = "/mhs_buffer.bin";

// Retransmission BORNEE par cycle : on ne rejoue qu'un lot limite de mesures
// historiques par reveil, pour ne pas transformer l'eveil en session illimitee
// (l'autonomie prime). Le reste se rattrape aux reveils suivants.
constexpr uint32_t SENSOR_RETX_MAX_PER_CYCLE = 10;

// Fenetre d'ecoute (ms) ouverte APRES l'envoi live pour recevoir le SyncControl
// du hub (accuse cumulatif + trou a combler). Courte et bornee : elle ne rallonge
// l'eveil que de ce delai au maximum, puis on retransmet et on dort.
constexpr uint32_t SENSOR_SYNC_RX_WINDOW_MS = 300;

// --- ESP-NOW Configuration ---
// SSID/mot de passe de l'AP du hub (identiques a ESPNOW_SOFTAP_* cote station).
// La sonde s'associe ici : plus de scan Livebox ni de lock canal promiscuous.
constexpr char ESPNOW_HUB_AP_SSID[] = "MH-NOW";
constexpr char ESPNOW_HUB_AP_PASS[] = "mhnowesp";   // = ESPNOW_SOFTAP_PASS du hub (config.h cote hub)

// Repli uniquement si le scan du SSID (secrets.h) n'a pas donne le canal AP.
constexpr uint8_t ESPNOW_WIFI_CHANNEL_FALLBACK = 1;
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

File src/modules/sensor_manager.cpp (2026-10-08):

#include "sensor_manager.h"
#include <Wire.h>

// Définition des variables statiques d'interruption
volatile uint32_t SensorManager::_anemometerPulses = 0;
volatile uint32_t SensorManager::_rainPulses = 0;

void IRAM_ATTR SensorManager::onAnemometerPulse() {
    _anemometerPulses++;
}

void IRAM_ATTR SensorManager::onRainPulse() {
    _rainPulses++;
}

SensorManager::SensorManager() {}

bool SensorManager::begin() {
    Serial.println("[SENSOR] Initialisation des capteurs...");

    // Si une broche d'alimentation dédiée aux capteurs existe, on l'active
    if (PIN_SENSOR_POWER >= 0) {
        pinMode(PIN_SENSOR_POWER, OUTPUT);
        digitalWrite(PIN_SENSOR_POWER, HIGH);
        delay(50); // Temps de stabilisation alimentation capteurs
    }

    // Initialisation du bus I2C
    if (!initI2C()) {
        Serial.println("[SENSOR] [WARN] Echec d'initialisation du bus I2C");
        return false;
    }

    // Détection des capteurs I2C
    _bmpFound = initBmp();

    _dht.begin();

    // Configuration des broches pour futures extensions (si configurées)
    if (PIN_ANEMOMETER_PULSE >= 0) {
        pinMode(PIN_ANEMOMETER_PULSE, INPUT_PULLUP);
        // attachInterrupt(digitalPinToInterrupt(PIN_ANEMOMETER_PULSE), onAnemometerPulse, FALLING);
    }

    if (PIN_RAIN_GAUGE_PULSE >= 0) {
        pinMode(PIN_RAIN_GAUGE_PULSE, INPUT_PULLUP);
        // attachInterrupt(digitalPinToInterrupt(PIN_RAIN_GAUGE_PULSE), onRainPulse, FALLING);
    }

    if (PIN_WIND_VANE_ADC >= 0) {
        pinMode(PIN_WIND_VANE_ADC, INPUT);
    }

    Serial.printf("[SENSOR] Bilan detection : BMP280=%s (DHT22 teste a chaque mesure)\n",
                  _bmpFound ? "OK" : "ABSENT");

    return true; // le DHT22 n'est pas detectable a part : chaque cycle retente
}

bool SensorManager::initI2C() {
    // Un seul Wire.begin : Adafruit rappelle begin() sans broches (defaut S3 = 8/9).
    Wire.begin(PIN_SENSOR_SDA, PIN_SENSOR_SCL);
    Wire.setClock(100000);
    delay(20);
    Serial.printf("[SENSOR] I2C  SDA=GP%u  SCL=GP%u\n", PIN_SENSOR_SDA, PIN_SENSOR_SCL);
    return true;
}

bool SensorManager::initBmp() {
    // 0x58 = BMP280, 0x60 = BME280 (meme lib, pression utilisable)
    const uint8_t addrs[] = {0x76, 0x77};
    const uint8_t ids[] = {0x58, 0x60};
    for (uint8_t addr : addrs) {
        for (uint8_t id : ids) {
            if (_bmp.begin(addr, id)) {
                _bmpAddr = addr;
                Serial.printf("[SENSOR] Capteur BMP/BME detecte 0x%02X id=0x%02X\n", addr, id);
                goto bmp_ok;
            }
        }
    }
    Serial.println("[SENSOR] [WARN] Capteur BMP/BME non detecte (0x76 / 0x77)");
    return false;

bmp_ok:

    // Reglage « weather monitoring » de la fiche technique Bosch : mode force,
    // suréchantillonnage x1, filtre IIR DESACTIVE. Avec une mesure toutes les
    // 5 min, un filtre IIR x16 lissait la pression sur plus d'une heure, ou
    // repartait de zero a un redemarrage (saut). La sonde doit rendre la reponse
    // REELLE du capteur : la qualification des mesures se fait plus haut (hub,
    // analyses), jamais ici. Le suréchantillonnage x1 suffit a la resolution
    // affichee (0,1 hPa) et raccourcit la conversion (moins d'eveil).
    _bmp.setSampling(Adafruit_BMP280::MODE_FORCED,
                     Adafruit_BMP280::SAMPLING_X1,    // Temperature
                     Adafruit_BMP280::SAMPLING_X1,    // Pression
                     Adafruit_BMP280::FILTER_OFF,     // Pas de filtre : reponse brute
                     Adafruit_BMP280::STANDBY_MS_500); // sans effet en mode force
    return true;
}

// DHT22 = reference temperature ET humidite (voir docs/notes.md, section 6). NaN = capteur absent
// ou trame invalide (checksum) : rien n'est publie, il n'y a plus de repli (l'AHT20 n'est plus lu).
bool SensorManager::readDht(float& temp, float& hum) {
    float h = _dht.readHumidity();
    float t = _dht.readTemperature();
    if (isnan(h) || isnan(t) || h <= 0.0f || h > 100.0f) return false; // DHT22 : 0 % = trame nulle
    hum = constrain(h + DHT22_HUM_OFFSET, 0.0f, 100.0f);
    temp = t + DHT22_TEMP_OFFSET;
    return true;
}

bool SensorManager::readPressure(float& pres) {
    if (!_bmpFound) {
        _bmpFound = initBmp();
        if (!_bmpFound) return false;
    }

    if (_bmp.takeForcedMeasurement()) {
        pres = _bmp.readPressure() / 100.0F; // Conversion Pa -> hPa
        return (pres > 300.0F && pres < 1100.0F);
    }
    return false;
}

void SensorManager::readWind(MeteoPacket& packet) {
    // Emplacement pour extension future Anémomètre / Girouette
    // Ex: calcul de la vitesse selon les impulsions comptées
    // packet.wind_speed = (float)_anemometerPulses * CALIBRATION_FACTOR;
    // packet.valid_fields |= FIELD_WIND_SPEED;
}

void SensorManager::readRain(MeteoPacket& packet) {
    // Emplacement pour extension future Pluviomètre
    // Ex: packet.rain_accumulated = (float)_rainPulses * BUCKET_MM_PER_PULSE;
    // packet.valid_fields |= FIELD_RAIN_TOTAL;
}
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

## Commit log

2026-09-13 Ajout de modèles de demande de fonctionnalité, de question et de rapport de bug pour améliorer la gestion des problèmes et des suggestions dans le projet.
2026-09-14 feat: Update battery management and ESP-NOW communication
    - Enhanced battery voltage monitoring with new minimum and maximum thresholds for different battery types.
    - Adjusted power management to skip channel recheck when battery is critically low.
    - Changed ESP-NOW communication to use unicast instead of broadcast for improved reliability and added channel scanning logic.
    - Updated configuration settings for measurement intervals and power levels based on board type.
    - Improved display output to show battery voltage alongside percentage.
    - Refactored code for clarity and maintainability, including better handling of channel changes and battery readings.
    [board_config.h, config.h, display_manager.cpp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]
2026-09-14 feat: Mise à jour de la version à 0.14.1 et ajout du contrat de packaging pour les cibles ESP32-S3 et ESP32-C3
2026-09-14 feat: Mise à jour de la version à 0.14.2 et amélioration de la documentation sur le câblage et l'autonomie
2026-09-14 feat: Mise à jour de la version à 0.15.1 et amélioration de la gestion de la batterie sur la carte ESP32-S3
2026-09-14 feat: Mise à jour de la version à 0.15.2 et ajustement de la calibration de la batterie par carte
2026-09-14 feat: Mise à jour de la version à 0.15.3 et correction d'un commentaire obsolète dans board_config.h
    [board_config.h]
2026-09-15 feat: Mise à jour des commentaires pour clarifier les spécifications de la cible Super Mini
2026-09-16 feat: Mise à jour de la version à 0.17.0, suppression de la cible ESP32-C3 et ajout de diagnostics dans le paquet ESP-NOW
2026-09-16 feat: Mise à jour de la version à 0.17.1, renommage de l'environnement de construction `supermini` en `esp32-s3` et mise à jour des documents associés
2026-09-16 feat: Mise à jour du manifeste de packaging pour renommer l'environnement de construction `supermini` en `esp32-s3` et suppression des cibles obsolètes
2026-09-16 feat: Mise à jour de la version à 0.17.2, correction du manifeste de packaging et mise à jour des fichiers README
2026-09-16 feat: Mise à jour de la version à 0.18.0, ajout du mode light sleep expérimental et mise à jour du changelog
2026-09-16 feat: Mise à jour de la version à 0.18.1, retour au mode deep sleep par défaut et mise à jour du changelog
2026-09-22 feat(sync): Implement MeasurementStore and BlobStore for persistent data handling
    - Introduced MeasurementStore for managing a ring buffer of sensor data with persistence.
    - Added BlobStore interface and MemoryBlobStore implementation for in-memory testing.
    - Created LittleFsBlobStore for handling data storage in Flash using LittleFS.
    - Integrated SyncManager to manage sequence numbers and timestamps, ensuring data integrity across power cycles.
    - Updated espnow_sender to utilize SyncManager for sequence management and control message handling.
    - Added unit tests for MeasurementStore to validate functionality including data persistence, overwriting behavior, and retransmission logic.
2026-09-22 feat: Mise à jour de la version à 0.21.0, ajout de la retransmission proactive et correction de la synchronisation
    [espnow_sender.cpp, main.cpp]
2026-09-22 feat: Mise à jour de la version à 0.22.0, ajout de la conversion des horodatages relatifs en absolus pour les retransmissions
2026-09-26 feat(pairing): Implement long press pairing mechanism and NVS storage
    - Added long press detection for the BOOT button to initiate pairing with a hub.
    - Implemented pairing logic to handle multiple hubs and ensure unique pairing.
    - Introduced NVS storage for saving and loading pairing records.
    - Enhanced ESP-NOW sender to manage pairing requests and confirmations.
    - Added unit tests for pairing logic, including response validation and handling ambiguous cases.
    - Updated power management to support waking from deep sleep via the BOOT button.
2026-09-26 feat: Mise à jour de la version à 0.23.1, ajout de la gestion des accusés incohérents et des tests associés
2026-09-26 feat: Update to version 0.24.0 with segmented logging and pairing improvements
    - Bump version from 0.23.1 to 0.24.0.
    - Enhance cablage documentation for pairing process.
    - Introduce segmented logging for sensor data, replacing the previous single file approach.
    - Implement new configuration parameters for segment retention and record management.
    - Refactor pairing logic to improve button press handling and prevent false triggers.
    - Update power management to handle stuck button scenarios.
    - Add new SegmentStore class for managing segmented data storage.
    - Implement LittleFsSegmentFs for file operations on LittleFS.
    - Create unit tests for SegmentStore functionality, including appending, ackn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
    [config.h, main.cpp, power_manager.cpp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]
2026-09-26 feat: Mise à jour de la version à 0.24.1, ajustement de la configuration du BMP280 pour un meilleur suivi météorologique
2026-09-26 feat: Mise à jour de la version à 0.25.0, amélioration de la gestion des sondes non appairées
2026-09-27 feat: Mise à jour de la version à 0.25.1, ajout de la gestion des secrets locaux et corrections diverses
    [board_config.h, main.cpp, meteo_packet.h]
2026-09-28 feat: Mise à jour de la version à 0.25.2, ajout de la gestion des lectures nulles du capteur AHT20
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2026-10-06 Add traditional Stevenson screen design for MeteoHubSensor
    - Introduced a new SCAD file for the mini Stevenson screen adapted for MeteoHubSensor.
    - Defined dimensions for the internal volume and external casing.
    - Implemented slats with specific angles and spacing for optimal air circulation.
    - Created modules for the structure, including posts, slats, lower frame, and roof.
    - Added electronic components representation within the design.
    - Included color definitions for various parts of the structure.
    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
    [mini_abri_meteohubsensor_STEVENSON_PLAN_TRADITIONNEL.scad]
2026-10-06 Add Stevenson shelter design for MeteoHubSensor
    - Defined dimensions, slats, and electronic components layout.
    - Implemented modules for posts, slats, roof, and electronics.
    - Ensured proper air circulation with slat design and open lower frame.
    - Included color definitions for various components.
    - Added comments for clarity on design choices and geometry verification.
    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
    [stevenson-shelter-v1.scad]
2026-10-06 Supprimer les fichiers de plan de l'abri Stevenson
    [mini_abri_meteohubsensor_STEVENSON_PLAN_TRADITIONNEL.scad]
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2026-10-09 Add new components and footprints for morfsensor project
    - Created 3D shapes for ESP32-S3 Super Mini Socket and Regulator Module 3V3 in VRML format.
    - Added KiCad symbol library for ESP32-S3 Super Mini with detailed pin configuration and properties.
    - Introduced footprints for ESP32-S3 Super Mini Socket and Regulator Module 3V3 with appropriate dimensions and pad configurations.
    - Updated symbol library table to include the new morfsensor library.
    [meteohubsensor-v1.kicad_pcb, meteohubsensor-v1.kicad_sch]
2026-10-10 Update 3D model and footprint for Regulator Module 3V3; add BOM documentation
    - Modified the 3D shape of the Regulator Module 3V3 to adjust dimensions and colors.
    - Updated the KiCad footprint for the Regulator Module 3V3, correcting pad positions and descriptions.
    - Added a comprehensive Bill of Materials (BOM) for the MeteoHubSensor v1, detailing components, quantities, and specifications.
    [meteohubsensor-v1.kicad_pcb, meteohubsensor-v1.kicad_sch]
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2026-10-10 fix: Correction de l'initialisation de la chaîne MD5 dans la fonction sealOtaOffer
    [meteo_packet.h]
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2026-10-10 fix: Mise à jour de la documentation OTA pour clarifier la gestion des offres de firmware
2026-10-22 fix: Suppression du module DisplayManager et de ses dépendances
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
